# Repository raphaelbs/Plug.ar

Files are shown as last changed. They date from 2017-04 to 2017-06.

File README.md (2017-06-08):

# Plug.ar

Plug.ar é um projeto de conclusão de curso desenvolvido por Raphael Brandão para a Faculdade Pitágoras.

# Descrição

A ideia base do projeto é o desenvolvimento de uma caixa de tomada conectada e modular.

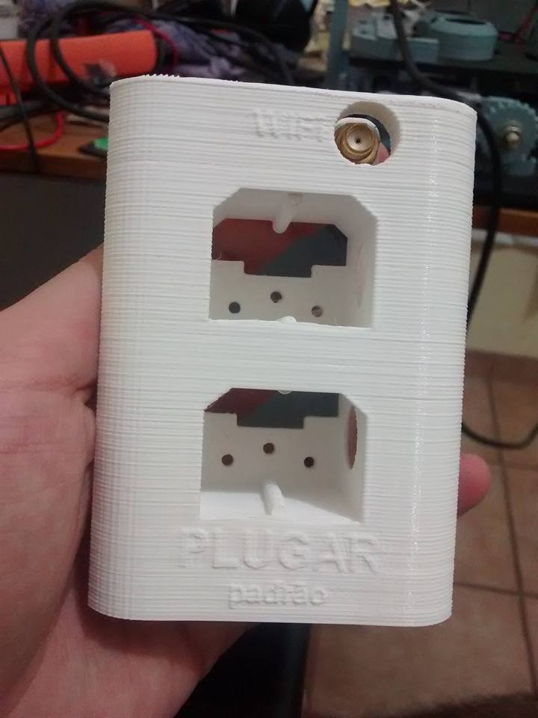
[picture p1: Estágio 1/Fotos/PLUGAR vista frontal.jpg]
Primeira versão do Plug.ar


_Primeira versão do Plug.ar_

### Conectividade

A caixa será concetada à internet através do ESP8266 e também criará uma rede HTTP interna. Esta rede HTTP interna será usada por outros dispositivos Plug.ar da mesma residência para realizar comunicação entre-si mesmo sem acesso à internet.

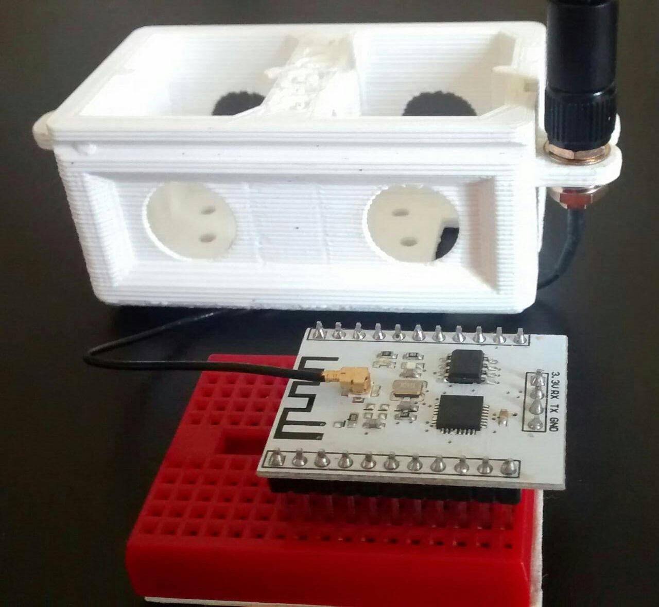
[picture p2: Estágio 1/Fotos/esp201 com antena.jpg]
Plug.ar e o ESP8266


_Plug.ar e o ESP8266_

### Modularização

A caixa de tomada será um container de módulos. O usuário final irá escolher qual módulo utilizar, quando necessário. Por exemplo, se o usuário deseja carregar o celular, poderá inserir um módulo de porta USB diretamente na sua tomada.

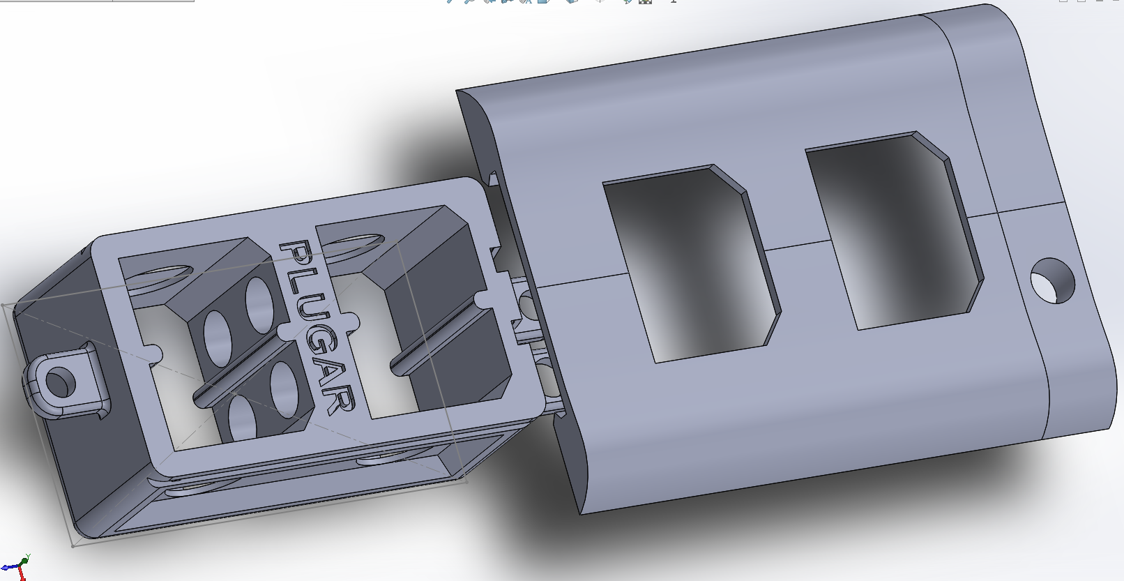
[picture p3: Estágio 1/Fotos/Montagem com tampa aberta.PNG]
Modularização do Plug.ar


_Modularização do Plug.ar_

# Etapas

O projeto conta com 3 etapas:
* [x] 2/2016 [**Estágio 1**](./Estágio%201) estruturação física do projeto com CAD e impressão 3D
* [x] 1/2017 [**Estágio 2**](./Estágio%202) prototipagem eletrônica e interligação com o projeto físico
* [ ] 2/2017 **TCC** desenvolvimento do firmware, cliente web e mobile

# Sobre

Estudante de Engenharia de Controle e Automação - Faculdade Pitágoras.
Gerente de Projetos e Full Stack Developer - Find Soluções Coorporativas LTDA.
Divinópolis, Minas Gerais, Brasil.

_raphael.b.souza@hotmail.com_

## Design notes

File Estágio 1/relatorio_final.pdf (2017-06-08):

### FACULDADE PITÁGORAS

RELATÓRIO DE ESTÁGIO CURRICULAR OBRIGATÓRIO

FACULDADE PITÁGORAS

Aluno: Raphael Brandão de Souza

Curso: Engenharia de Controle e Automação

Matrícula: 828587

Divinópolis

2016

1

RAPHAEL BRANDÃO DE SOUZA

RELATÓRIO DE ESTÁGIO CURRICULAR OBRIGATÓRIO

GUILHERME OTÁVIO FERREIRA FARIA

Relatório de Estágio Curricular apresentado à Faculdade

Pitágoras como requisito parcial do curso de Engenharia de

Controle e Automação.

Coordenador de Curso:

Danielle Comitante Leão Fontes

Divinópolis

2016

2

### FACULDADE PITÁGORAS

Relatório de Estágio Curricular Obrigatório em 2016

Dados do Estagiário

### Nome: Raphael Brandão de Souza

### Registro Acadêmico: 828587

### Curso e Período: Engenharia de Controle e Automação, 8° Período

Dados do Local de Estágio

### Empresa: Guilherme Otávio Ferreira Faria

### Supervisor: Guilherme Otávio Ferreira Faria

### N° de registro: 200649/LP

Período de Estágio

Início: 19/09/2016 | Término: 24/10/2016

Jornadas de trabalho: 30 horas semanais.

Total de horas: 150 horas em 25 dias úteis.

Divinópolis

2016

3

SUMÁRIO

4

### 1 INTRODUÇÃO

O presente trabalho tem como objetivo apresentar o projeto, denominado PLUGAR,

cumprindo a primeira de duas fases da disciplina de Estágio Supervisionado I, que tem como

supervisor o engenheiro Guilherme Otávio Ferreira Faria. Ressalta-se que este projeto é parte

integrantes das disciplinas acadêmicas que estão sendo e serão cursadas na Faculdade Pitágoras

pelo aluno Raphael Brandão do curso de Engenharia de Controle e Automação.

1.1 CENÁRIO

Com a crescente inclusão digital, a necessidade de agregar componentes do dia-a-dia

no mundo digital está sempre em demanda. A Internet das Coisas é um termo que está sendo

repetido cada vez mais nos artigos acadêmicos, nas redes de notícias, projetos de financiamento

coletivo, colaborações open-source, etc. Por definição, Internet das Coisas (IoT - Internet of

Things em inglês) é sinônimo da agregação de componentes simples, básicos e offlines como

geladeiras, carros, cortinas, entre outros, em um ambiente online, controlado e integrado.

Através desta virtualização é possível assumir o controle, economizar tempo, poupar esforços,

em qualquer lugar a qualquer momento, utilizando desde seu smartphone até soluções ainda

mais engenhosas; dependendo apenas da aplicação.

Desta forma, o projeto PLUGAR apoia-se nessa cultura, captando todos os benefícios

de transformar o conceito simplório e estático das tomadas residenciais em um sistema

complexo, integrado, compartilhado e dinâmico, permitindo maximizar o potencial manual e

fixo de controle dos eletrodomésticos, luzes e eletroeletrônicos transformando-os em

componentes vivos de um sistema.

O objetivo cumprido neste estágio inclui a modelagem, análise e impressão 3D do

componente estrutural, planejamento inicial da eletrônica lógica e eletrônica de potência da

placa de circuito impresso do PLUGAR.

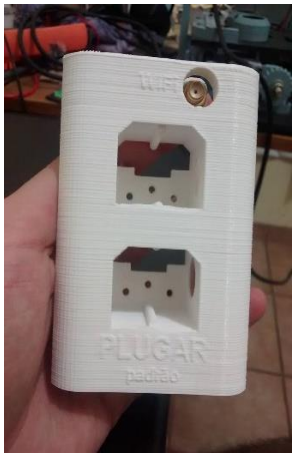
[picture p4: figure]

5

1.2 SOBRE O PLUGAR

PLUGAR é conectar, é vincular, é agregar. O termo reforça a ideia de que é necessária

uma reformulação dos pontos de tomadas e interruptores, a fim de alcançar uma maior

abrangência nas funcionalidades, trazendo tecnologia e maiores níveis de conforto e ergonomia

se comparado ao padrão atual. Este utiliza de recursos manuais e fixos, como por exemplo, o

novo plugue de tomada elétrica de três pinos, regulamentado pela NBR 14136 (Plugues e

tomadas para uso doméstico e análogo até 20A/250V em corrente alternada - padronização).

Além do alto custo, a alteração do padrão gera um movimento desnecessário na indústria para

refatoração dos produtos homologados. No final das contas, além do fato de prejudicar o

consumidor financeiramente por requerer renovação dos produtos adquiridos ou transporte de

adaptadores, este padrão não conta com nenhum tipo de inserção no meio tecnológico.

Unificando os padrões de tomada, o PLUGAR

também adiciona flexibilidade em um novo modelo que

funciona sob a demanda do usuário e inclui tecnologia de

ponta nas residências tirando vantagem da estrutura existente

dos modelos atuais e modificando diretamente a maneira

como interagimos com nossas residências. O objetivo do

dispositivo é integrar, em rede doméstica e na internet, pontos

de interruptores e tomadas, com capacidade à expansão para

pontos de telefone, ethernet, etc. Para incrementar a

usabilidade do dispositivo, o PLUGAR foi projetado com o

ideal de modularidade. Além de funcionar como contêiner de

módulos que variam em funcionalidade, o design do

dispositivo também pode ser adaptado e estendido para fins

específicos (Figura 1).

Figura 1 - PLUGAR visto de frente Fonte: Imagem do autor

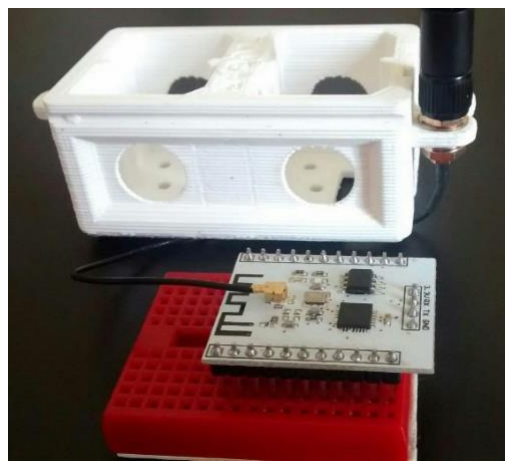
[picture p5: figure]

6

1.3 | TECNOLOGIA APLICADA AO PLUGAR
| Para embasar os conceitos técnicos, deve-se mencionar as referências que se seguem.

1.3.1 MICROCONTROLADORES

Um microcontrolador é um sistema computacional completo, no qual estão incluídos

uma CPU (Unidade de processamento central), memória de dados e programa, um

sistema de clock, portas de I/O (Entrada/Saída), além de outros possíveis periféricos,

tais como, módulos de temporização e conversores A/D entre outros, integrados em

um mesmo componente. (DERNARDIN, [2005], p. 2)

1.3.2 ESP8266 VERSÃO ESP-201

ESP8266 é um microcontrolador com Wi-Fi embutido. Conta com conectores GPIO,

barramentos I2C, SPI, UART, entrada ADC, saída PWM e sensor interno de temperatura. Sua

CPU opera em 80MHz, com possibilidade de operar em 160MHz. Possui arquitetura RISC de

32 bits, 32KBytes de RAM para instruções, 96KBytes de RAM para dados, 64KBytes de ROM

para boot. Possui uma memória Flash SPI Winbond W25Q40BVNIG de 512KBytes. O núcleo

é baseado no IP Diamand Standard LX3 da Tensilica.

Fabricado pela Espressif, existem módulos de diferentes

tamanhos e fabricantes.

O módulo utilizado neste projeto é o ESP-201.

Além das características citadas acima possui dois tipos de

antena: embutida ou conector para UF-L. Também conta

com pinagem padrão de protoboard (distância entre pinos

de 2.54mm) com dimensão totalizando 34x25x3,5mm

(Figura 2).

Figura 2 - ESP8266 versão ESP 201
| Fonte: Imagem do autor

7

1.3.3 PROTOCOLO I2C

O protocolo I2C descreve o funcionamento de um barramento de comunicação serial que utiliza

apenas dois fios, inventado pela Philips no início da década de 90, este protocolo é muito

utilizado para conectar periféricos de baixa velocidade a placas-mãe, microcontroladores e afins.

Tanto a unidade de controle quanto os periféricos devem possuir implementação e suporte I2C,

seja via hardware no próprio microcontrolador ou utilizando CI’s externos como o SC16IS750,

ou até mesmo via software, através de um método chamado bit-bang, onde o funcionamento do

protocolo é emulado bit a bit. (CAMARA, 2013, p.1)

1.3.4 CI PCF8574

O circuito integrado PCF8574 é um extensor de portas entradas/saídas. Funciona sobre

a interface de comunicação I2C, simplificando o circuito em apenas duas portas: serial clock

(SCL) e serial data (SDA).

Com ele é possível expandir as portas de um microcontrolador utilizando apenas essas

duas portas para emular o controle de até 8 portas. Comunica com outros dispositivos I2C

conectados através do registrador que pode conter até 8 estados, uma para cada porta.

1.3.5 PLA

PLA é um material biodegradável produzido a partir de fontes naturais tais como cana

de açúcar e milho, utilizado como matéria prima de impressoras 3D. Grandes peças impressas

com PLA apresentam dimensões precisas e não sofrem com o efeito warp (resfriamento rápido

do material que causa contração). Emite um odor característico de açúcar e não emite nenhum

gás tóxico como pode ser o caso de outros filamentos derivados de plástico.

8

1.4 CONCEITO FUNCIONAL

Cada dispositivo PLUGAR é uma central autônoma capaz de fisicamente controlar os

módulos e integra-los em rede doméstica e/ou via Internet. Para controle e interface com WiFi

o microcontrolador ESP8266 (na sua versão ESP-201) atende os requisitos e se demonstra ideal

pelo baixo custo e integração. A ponte entre o microcontrolador e módulos será feita através do

protocolo I2C utilizando o circuito integrado PCF8574, permitindo a conexão paralela de até 8

módulos sobre o mesmo barramento, reduzindo a complexidade do circuito impresso e

agregando facilidades na padronização dos módulos. No cenário do PLUGAR, um CI I2C de 4

bits atenderia os requisitos.

Os módulos do PLUGAR serão desenvolvidos cada um com sua eletrônica interna,

porém a estruturação do modelo para a eletrônica dos mesmos não será abordada neste trabalho.

1.4.1 ESTRUTURAL

Os componentes estruturais do PLUGAR irão habitar dois tipos de ambientes, o interior

dos pontos de tomada, parcialmente escondido das vistas, e o exterior do ponto de tomada, se

tornando uma ferramenta de design da residência. Neste relatório estão descritas as atividades

desenvolvidas para realização dos componentes estruturais Contêiner e Tampa (Tabela 1).

Tabela 1 - Referência dos componentes, suas funções e localizações

Componente | Função | Localização
Contêiner (Figura 3) | Principal estrutura do PLUGAR. Responsável por substituir a estrutura dentro da caixa de tomada; interliga todos os demais componentes entre si; fixa e conecta o circuito eletrônico com o componente Módulo. Também é estrutura de apoio para o componente Tampa. | Fixado dentro da caixa de tomada.
Tampa | A Tampa além de funcionar como estrutura de design | Encaixado no

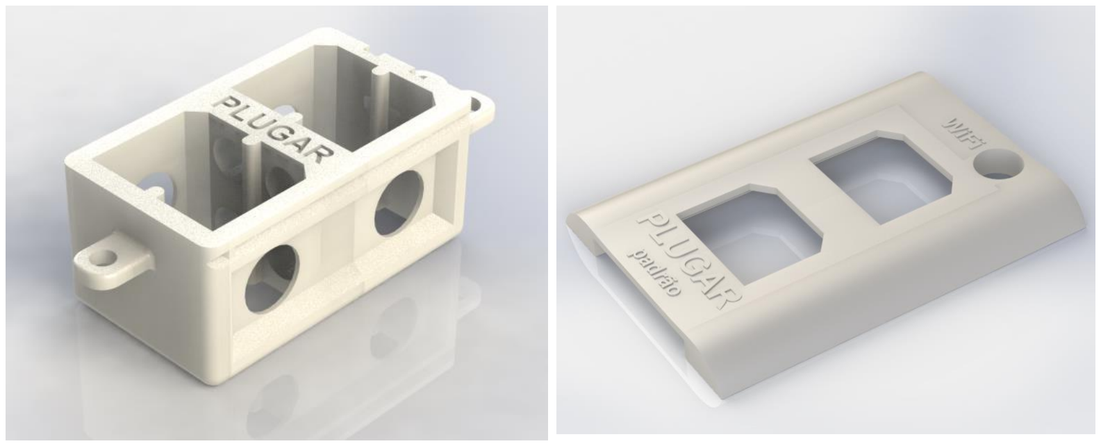
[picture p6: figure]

9

(Figura 4) | também funciona como fixador do componente Módulo dentro do componente Contêiner e como interruptor geral do PLUGAR. Pode assumir formatos variados para incrementar o design do ambiente. | Contêiner.
Módulo | O Módulo é o componente físico que oferece a flexibilidade que o ambiente virtual necessita. Cada Módulo possui sua determinada função e pode ser facilmente substituído do componente Contêiner, basta retirar o componente Tampa, remover o Módulo atual e inserir o desejado. | Inserido no Contêiner.

Fonte: Elaborado pelo autor

Figura 3 - Componente Contêiner, renderizado Fonte: Imagem do autor

Figura 4 - Componente Tampa, renderizado Fonte: Imagem do autor

10

1.4.2 ELETRÔNICA

Do objeto funcional do circuito eletrônico do PLUGAR destaca-se a capacidade de

interligar o microcontrolador ESP8266 versão ESP-201, a cavidade dos módulos e as fontes de

tensão.

O circuito é capaz de converter corrente alternada de alta tensão em corrente contínua

de tensões 5v e 3.3v, redistribuir as faixas de tensões DC e AC para os módulos além de

implementar o barramento I2C para comunicação.

Tabela 2 - Detalhamento dos componentes eletrônicos e suas funções

Nome | Descrição | Características
HLK-PM12 (Figura 5) | Conversor integrado AC para DC. | • Opera com tensões AC entre 90v e 264v. • Eficiente, perde menos que 0.1W quando em standby. • Fornece 600mA de corrente estavelmente e aguenta picos de 1A.
L4931 (Figura 6) | Regulador de tensão pacote TO-92. | • Regula tensões com até 2% de tolerância. • Corrente máxima de 300mA com circuito interno limitador de corrente e switch térmico.
BCI 006 1E-6 (Figura 7) | Barra de pinos macho-fêmea padrão protoboard com 6 saídas. | • Conector de encaixe linear. • Baixo custo.
Terminais parafusados (Figura 8) | Borne integradas com circuito impresso. | • Praticidade • Baixo custo

Fonte: Elaborado pelo autor

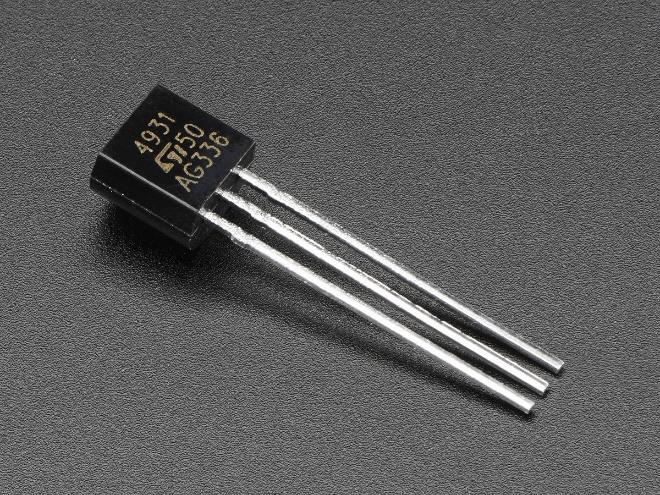
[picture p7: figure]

11

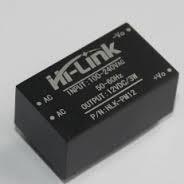
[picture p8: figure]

Figura 5- HLK-PM12
Fonte: http://www.hlktech.net/product_detail.php?ProId=56

Figura 6 - L4931.
Fonte: https://www.adafruit.com/product/2236

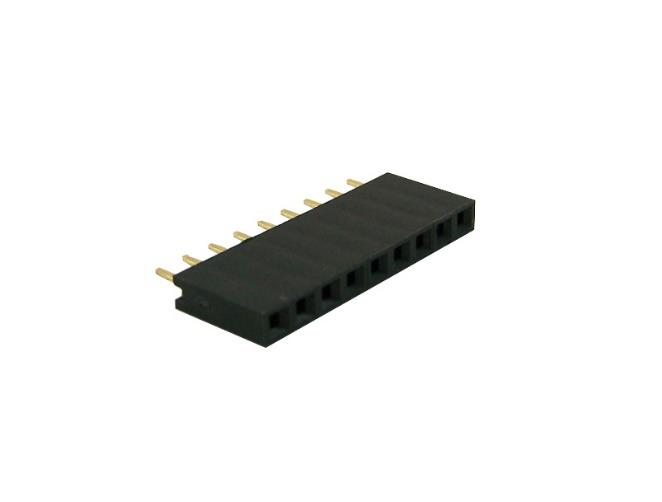
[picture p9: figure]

Figura 7 - BCI 006 1E-6
Fonte: http://www.eletrodex.com.br/barra-conectora-de-pino-estampado-simples-180-2-a-40-pinos.html (http://www.eletrodex.com.br/barra-conectora-de-pino-estampado-simples-180-2-a-40-pinos.html)

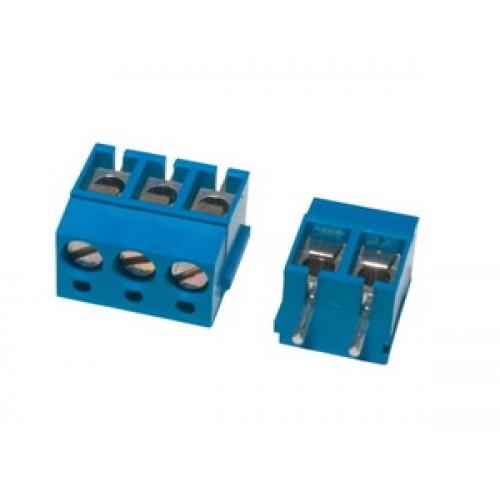
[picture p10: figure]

Figura 8 - Terminais parafusados
Fonte: http://www.taydaelectronics.com/dg300-screw-terminal-block-2-positions-5mm.html (http://www.taydaelectronics.com/dg300-screw-terminal-block-2-positions-5mm.html)

### 2 AMBIENTE DE ESTÁGIO

Guilherme Otávio Ferreira Faria é membro colaborador de uma firma autônoma

prestadora de serviço na área de engenharia e construção civil.

A firma realiza projetos arquitetônicos, projetos elétricos, projetos de prevenção e

combate a incêndio, projetos estruturais e planejamentos e execuções de obras. Presta serviço

para Francisco Imóveis, Martins Empreendimentos, Construtora e Incorporadora Predisul,

Construtora e Incorporadora Premium, dentre outros. Situa-se na Rua Pernambuco, número 50,

bairro Centro da cidade de Divinópolis. Sua missão é executar com maestria obras e projetos

na área de construção civil.

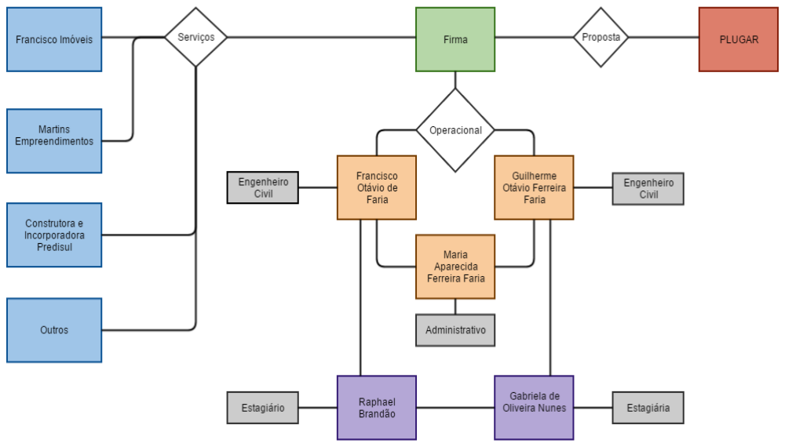
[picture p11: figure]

12

Atualmente, buscando expandir a abrangência na prestação de serviço, realizou-se uma

parceria para desenvolver um projeto de automação residencial: o PLUGAR, combinando a

expertise dos serviços realizados pela firma e o conhecimento do aluno aplicado na área de

automação, controle, modelagem, eletrônica e impressão 3D.

O ambiente de estágio conta com estações de qualidade uma vez que na empresa são

utilizados softwares robustos de CAD para o desenvolvimento dos projetos de engenharia civil.

2.1 | ORGANOGRAMA
| De acordo com o ambiente de estágio citado no item 2, foi possível estabelecer um

organograma, no qual apresenta a organização hierárquica da empresa, seus setores e

funcionamentos por meio de cores (Figura 9).

Figura 9 - Organograma da firma Fonte: Elaborado pelo autor

13

### 3 ATIVIDADES DESENVOLVIDAS

### 19/09/2016 – Apresentação

Introdução à metodologia, ambientação e compartilhamento dos recursos necessários para o

desenvolvimento durante o estágio.

### 20/09/2016 – Resolução conceitual

Apresentação dos conceitos, desafios técnicos, áreas de atuação para desenvolvimento do

projeto, recursos necessários e capacidades requeridas.

### Período de 21/09/2016 a 22/09/2016 – Discussão e detalhamento

Estruturação inicial das etapas necessárias para desenvolvimento linear do projeto.

Observações sobre a necessidade do primeiro esboço técnico do circuito impresso para

modelagem do modelo estrutural. Padronização para o tamanho do contêiner com

40x70x32mm. Contemplação e subdivisão do cronograma do projeto no tempo das etapas do

estágio supervisionado e trabalho de conclusão de curso que se seguem entre o segundo

semestre de 2016 ao segundo semestre de 2017.

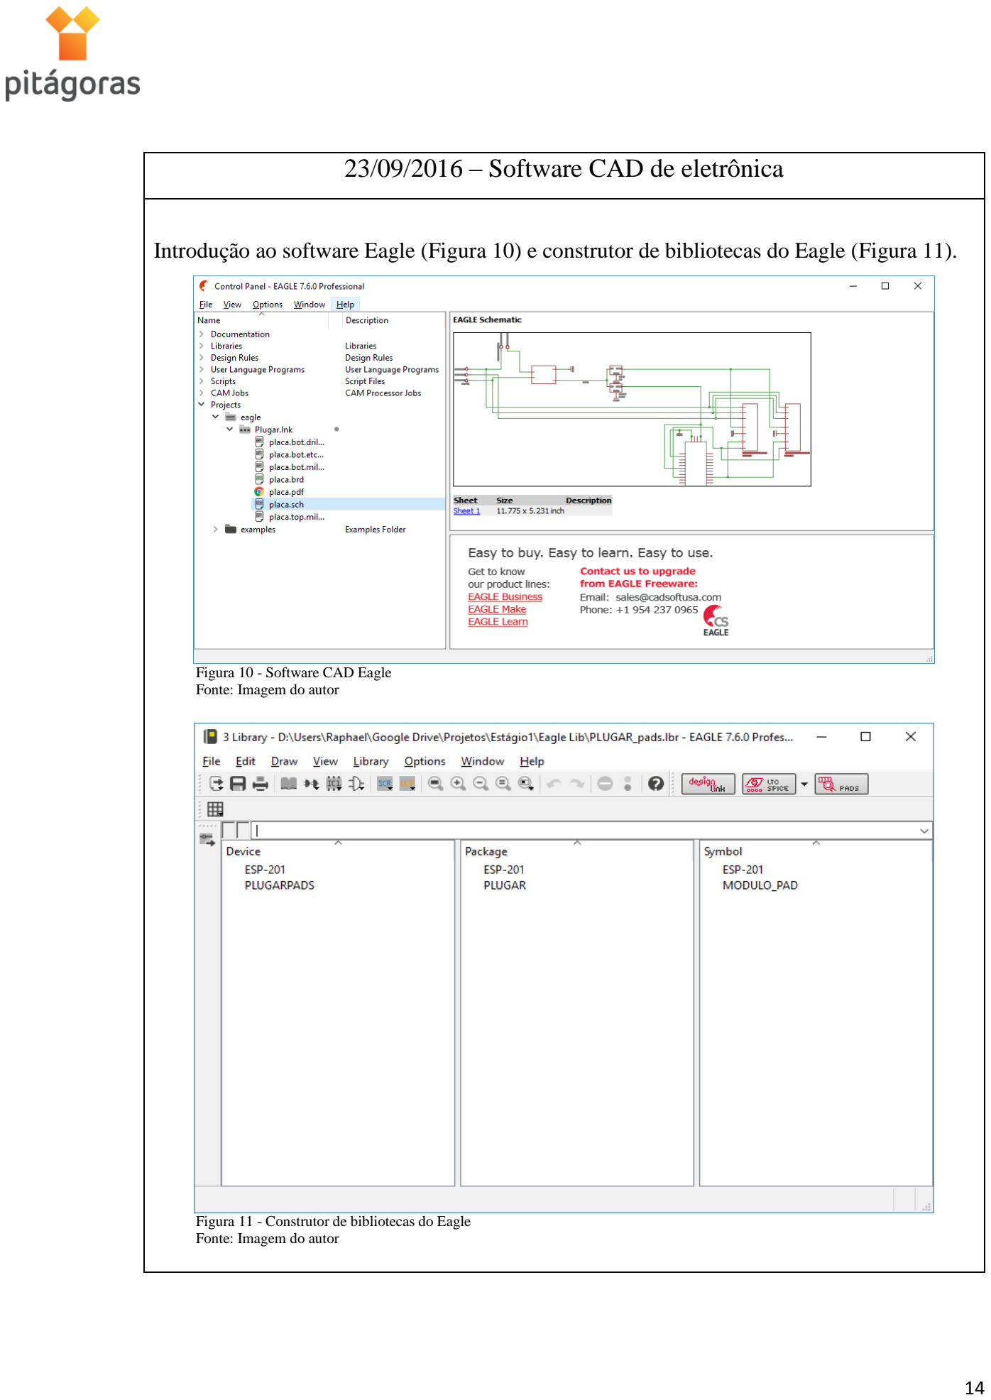
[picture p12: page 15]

14

### 23/09/2016 – Software CAD de eletrônica

Introdução ao software Eagle (Figura 10) e construtor de bibliotecas do Eagle (Figura 11).

Figura 10 - Software CAD Eagle Fonte: Imagem do autor

Figura 11 - Construtor de bibliotecas do Eagle Fonte: Imagem do autor

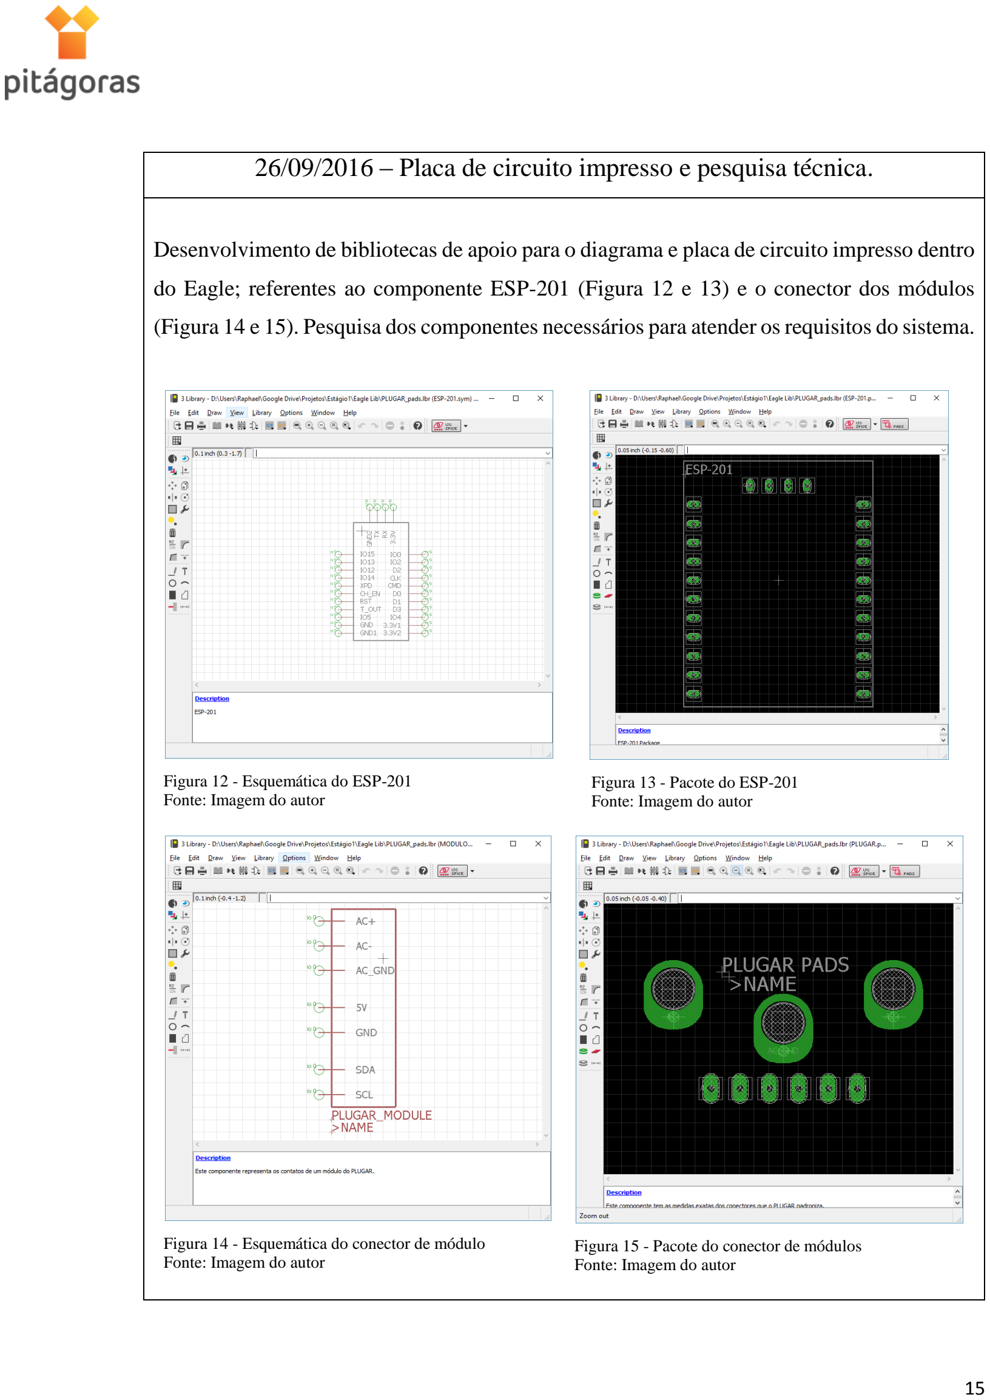
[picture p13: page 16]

15

26/09/2016 – Placa de circuito impresso e pesquisa técnica.

Desenvolvimento de bibliotecas de apoio para o diagrama e placa de circuito impresso dentro

do Eagle; referentes ao componente ESP-201 (Figura 12 e 13) e o conector dos módulos

(Figura 14 e 15). Pesquisa dos componentes necessários para atender os requisitos do sistema.

Figura 12 - Esquemática do ESP-201 Fonte: Imagem do autor

Figura 13 - Pacote do ESP-201 Fonte: Imagem do autor

Figura 14 - Esquemática do conector de módulo Fonte: Imagem do autor

Figura 15 - Pacote do conector de módulos Fonte: Imagem do autor

16

### 27/09/2016 – Placa de circuito

Integração dos componentes escolhidos no circuito esquematizado (Figura 16) com base nas

medidas pré-estabelecidas (Figura 17). Modelagem da placa de circuito impresso (Figura 18).

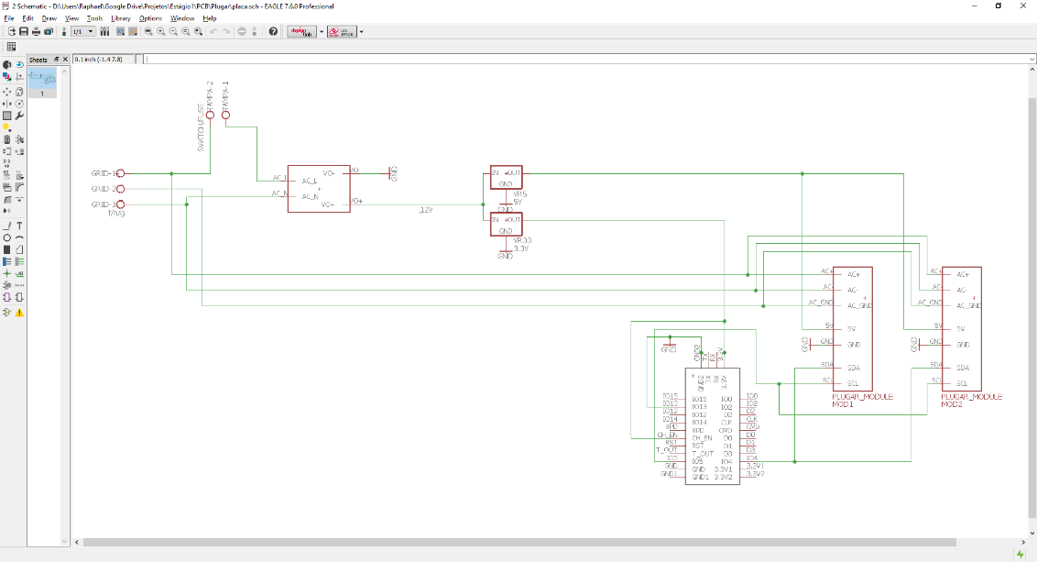
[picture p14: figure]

Figura 16 - Esquema eletrônico Fonte: Imagem do autor

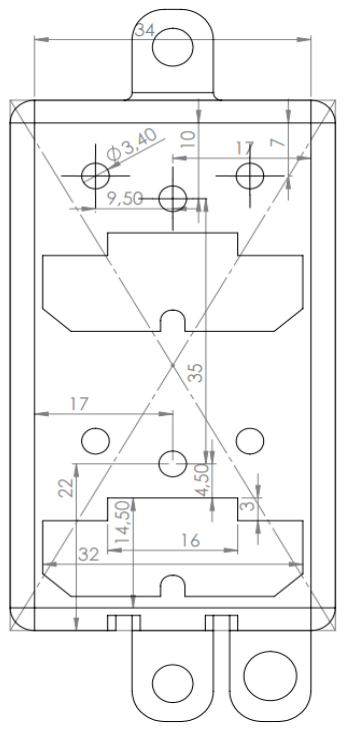
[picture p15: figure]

Figura 17 - Padrão estabelecido Fonte: Imagem do autor

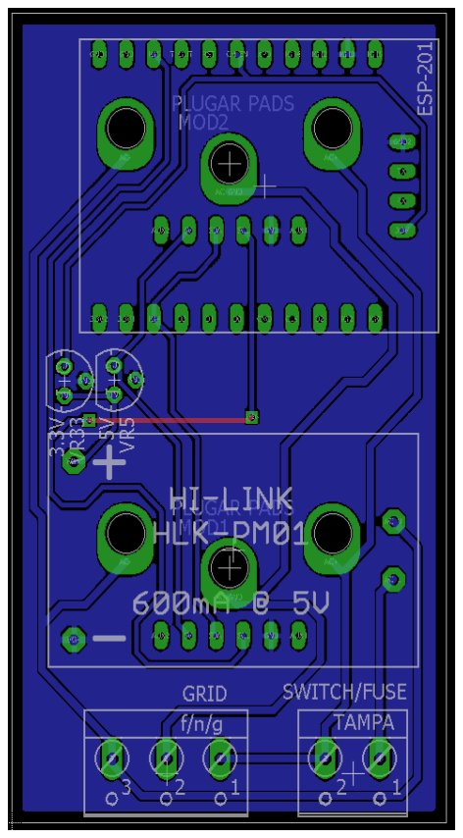
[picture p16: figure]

Figura 18 - Placa de circuito impresso do PLUGAR
. | Fonte: Imagem do autor

17

### 28/09/2016 – Introdução ao CAD 3D

Conferência do modelo gerado através do software Eagle com o padrão desejado. Introdução

ao software de modelagem 3D SolidWorks (Figura 19).

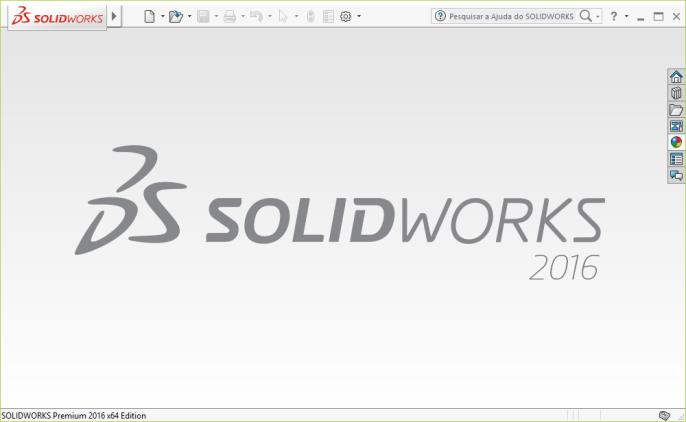
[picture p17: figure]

Figura 19 - Software CAD 3D Solidwoks Fonte: Imagem do autor

### Período de 29/09/2016 a 05/10/2016 – Componente Contêiner

Com base no modelo eletrônico e o desenho técnico do padrão estabelecido, foi desenvolvido

o componente estrutural Contêiner (Figura 20) contemplando métrica para conter os

componentes Módulos, orelhas fixadoras de parede, orelhas fixadoras para a antena, conceito

para trilha de contato liga/desliga de ação com o componente Tampa e trilha de apoio para o

componente Tampa.

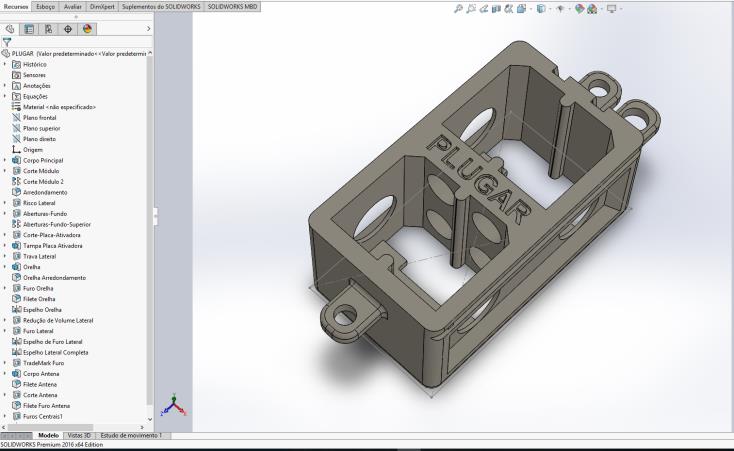
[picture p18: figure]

Figura 20 - Componente Contêiner, segunda versão Fonte: Imagem do autor

18

### Período de 06/10/2016 a 10/10/2016 – Componente Tampa

Implementação do componente Tampa (Figura 21) com design orgânico, furação para uso

dos módulos e da antena, trilha para apoio no componente Contêiner e implementação dos

textos informativos. Avaliação do resultado obtido.

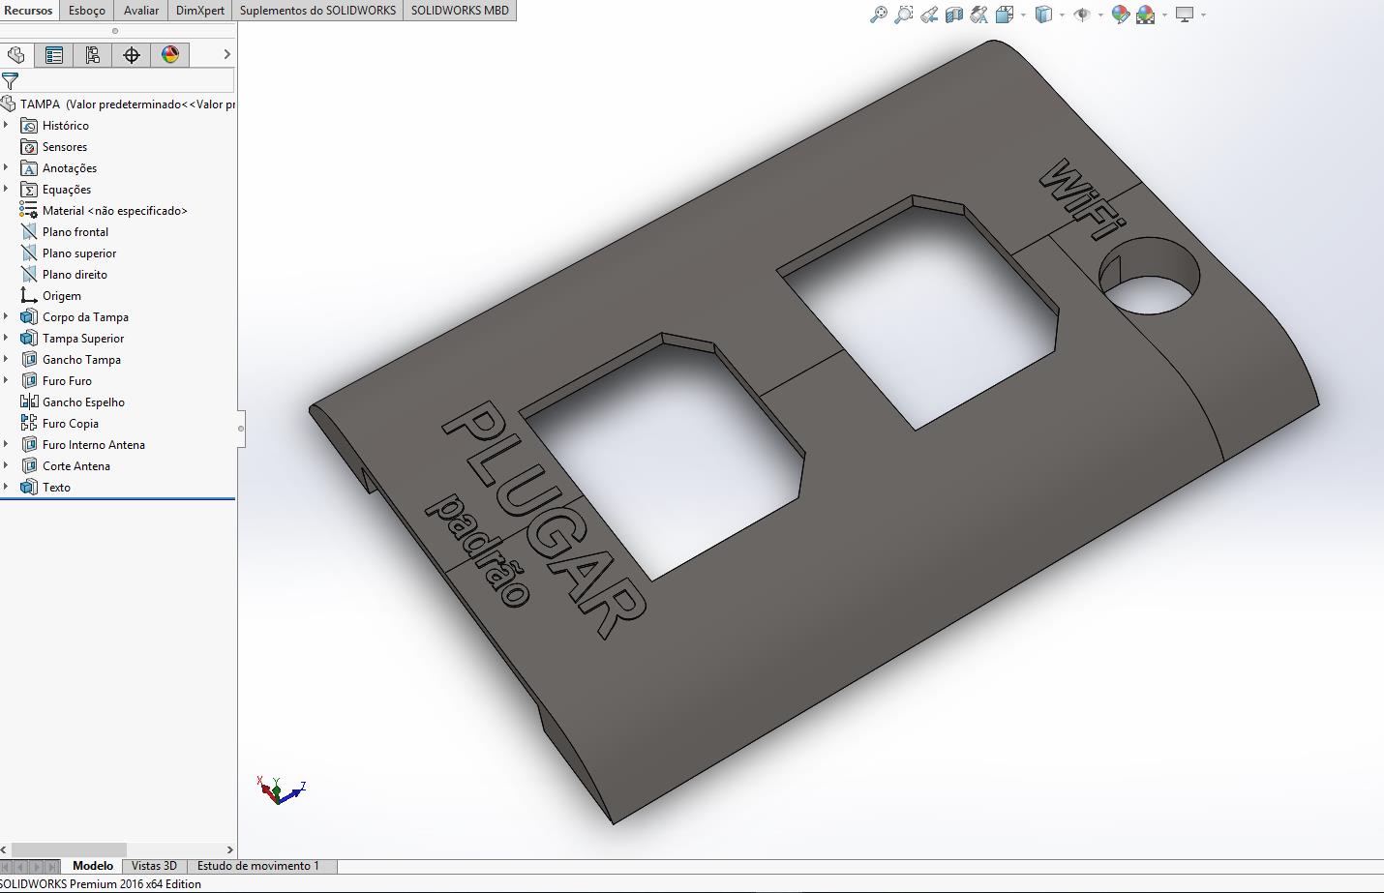
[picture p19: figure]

Figura 21 - Componente Tampa, segunda versão Fonte: Imagem do autor

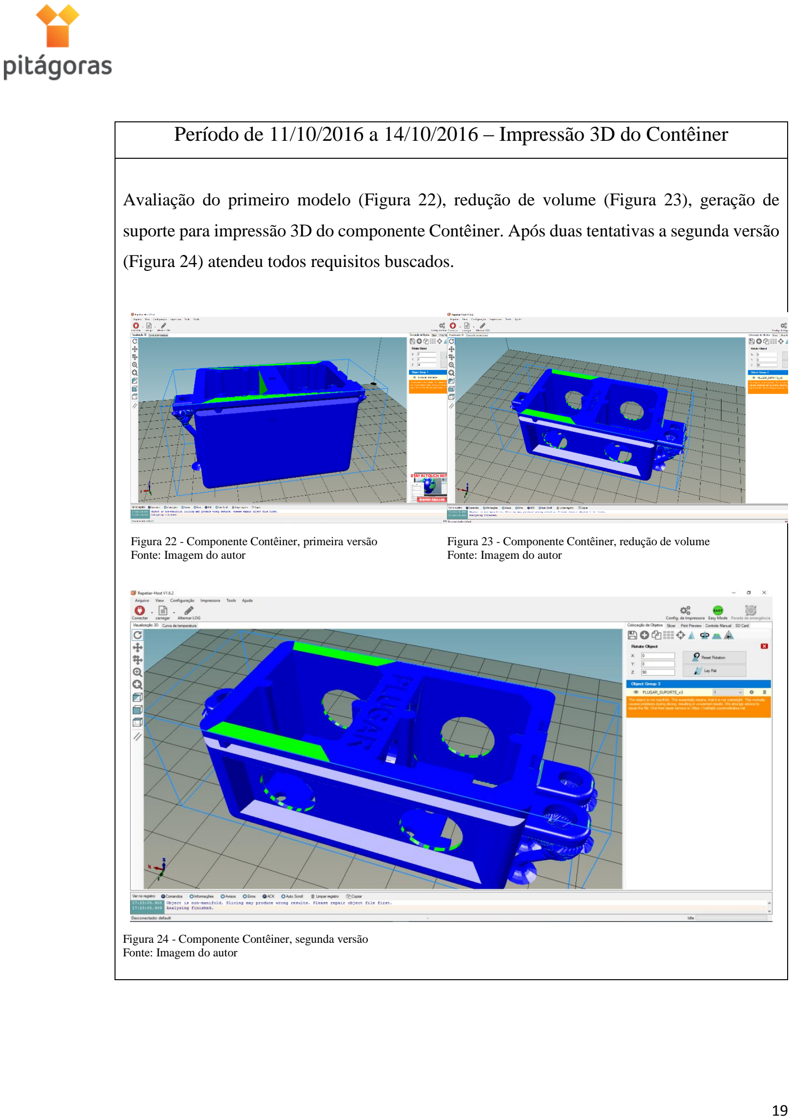
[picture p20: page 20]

19

### Período de 11/10/2016 a 14/10/2016 – Impressão 3D do Contêiner

Avaliação do primeiro modelo (Figura 22), redução de volume (Figura 23), geração de

suporte para impressão 3D do componente Contêiner. Após duas tentativas a segunda versão

(Figura 24) atendeu todos requisitos buscados.

Figura 22 - Componente Contêiner, primeira versão Fonte: Imagem do autor

Figura 23 - Componente Contêiner, redução de volume Fonte: Imagem do autor

Figura 24 - Componente Contêiner, segunda versão Fonte: Imagem do autor

20

### Período de 17/10/2016 a 18/10/2016 – Componente Tampa

Avaliação do primeiro modelo (Figura 25), conferência do encaixe com o componente

Contêiner, adequação e impressão da segunda versão com folga no trilho e aumento do

orifício da antena (Figura 26).

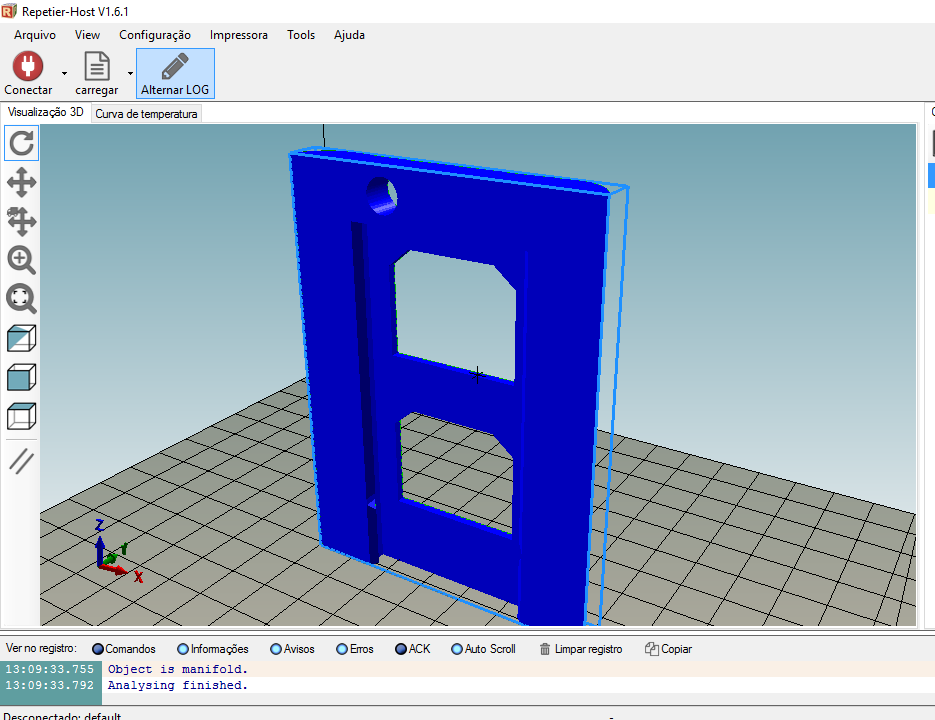
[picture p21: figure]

Figura 25 - Componente Tampa, primeira versão Fonte: Imagem do autor

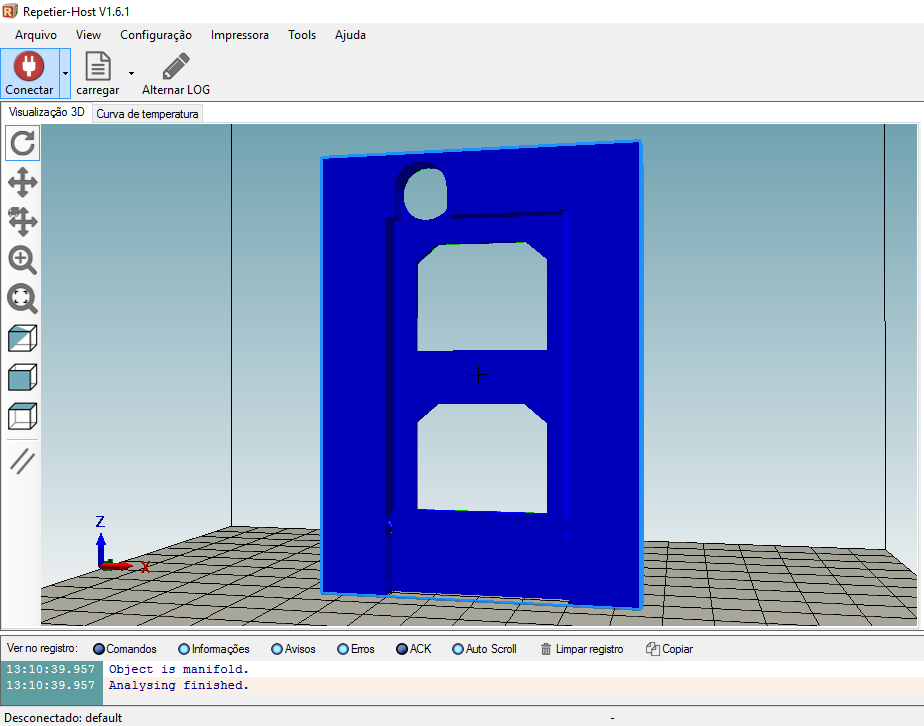
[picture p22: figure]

Figura 26 - Componente Tampa, segunda versão Fonte: Imagem do autor

21

### 20/10/2016 – Análise de desempenho dos modelos estabelecidos

Com base nas versões previamente estabelecidas, fora testado o atendimento dos objetivos

requeridos. O encaixe do componente Contêiner para o componente Tampa está funcional,

contando com travas que cumpriram sua função (Figura 27); a altura do componente

Contêiner ficou correta para atender o padrão das caixas de tomada (Figura 29); métrica do

componente Tampa ficou dentro dos padrões atuais (Figura 28).

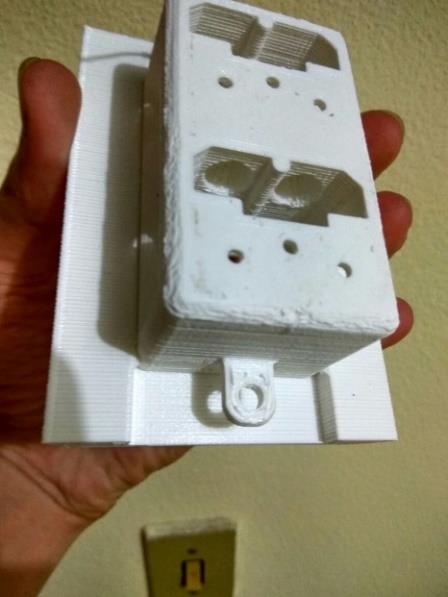
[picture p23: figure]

Figura 27 - Encaixe da Tampa no Contêiner. Fonte: Imagem do autor

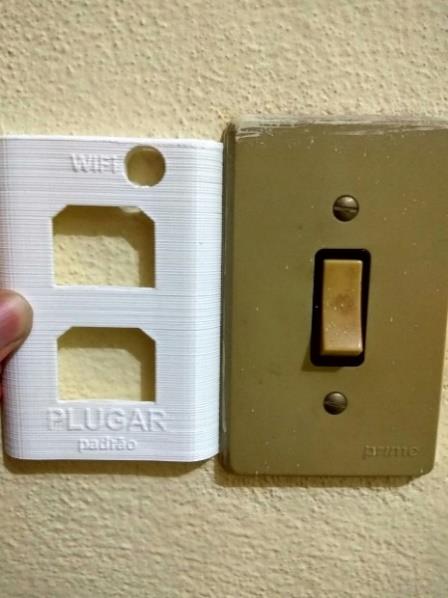
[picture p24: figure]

Figura 28 - Comparativo do componente Tampa com uma tampa de tomada.
Fonte: Imagem do autor

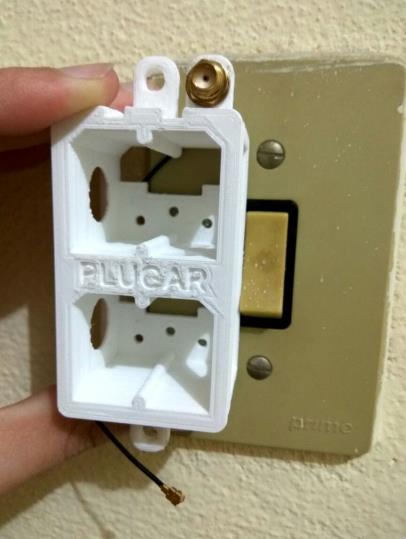
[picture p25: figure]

Figura 29 - Comparativo superficial do componente Contêiner com uma tomada Fonte: Imagem do autor

22

### 4 DISCUSSÕES GERAIS

Com a popularização dos movimentos Maker pelo mundo, a difusão da tecnologia open-

source reflete em qualificação técnica informal e gratuita. Gera uma cadeia de consequências,

desde novas ideias, novos produtos até novos padrões de mercado na própria comunidade.

Grandes contribuições do mundo Maker devem ser citadas aqui pois são cruciais para o projeto

PLUGAR. Os padrões de componentes de impressora 3D possibilitaram a montagem da

impressora 3D Graber i3 utilizada no estágio. Com a ajuda deste recurso foi possível expandir

o projeto para o meio físico, testando iterações dos modelos até encontrar os resultados

desejados.

4.1 | DO PROJETO
| O PLUGAR evoluiu de um pressuposto inicial simples, sem modularização, apenas com

conceito de integração com a internet. Evoluiu em sua estrutura física e ainda conta com um

grande caminho a percorrer quanto a implementação do sistema de controle, a agregação e

montagem dos componentes.

| Os recursos utilizados no projeto proveram tanto da empresa quanto do aluno. Os

softwares pagos como Eagle e Solidworks foram utilizados na empresa por serem licenciados

para uso doméstico e comercial. Os softwares livres tais como Repetier Host, Slic3r,

Meshmixer e Blender foram utilizados pelo aluno. A impressora 3D é propriedade do aluno,

porém toda prototipagem fora feita sob supervisão do engenheiro para avaliação do

atendimento dos requisitos.

4.2 DO AMBIENTE DE ESTÁGIO

Sendo amigos de longa data, o relacionamento entre supervisor e aluno se mostrou

simplificado, divertido e direto. A troca de informações, conhecimento e opiniões é suavizada

pela familiaridade com o companheiro de serviço tanto no momento de delegar funções quanto

no momento de buscar ajuda.

23

Mesmo atarefado constantemente em projetos paralelos o supervisor do estágio soube

repassar e avaliar as atividades no momento necessário e assegurou o cumprimento do

cronograma estabelecido.

### 5 CONSIDERAÇÕES FINAIS

Inspirado em novas vertentes do setor de tecnologia, o projeto PLUGAR se mostrou

como um desafio, bem como, excelente ponto de iniciação no mercado profissional, embasando

novas áreas além da capacitação curricular do aluno e expandindo a área de interesse e atuação

do mesmo. Participar, desenvolver e criar, desde o conceito até a realidade, foram metodologias

de trabalho gratificantes e, de certa forma, pioneiras.

Por meio do estágio supervisionado, que se finaliza através da documentação de relatório, foi

possível alcançar um aprendizado extracurricular além de instigar e fomentar o estudo e

interesse em diferentes áreas ímpares às comuns.

### 6 REFERÊNCIAS

ALLDATASHEET, L4931 – Very Low Dropout Voltage Regulator, Datasheet (PDF) –

STMicroeletronics. Disponível em

<http://pdf1.alldatasheet.com/datasheet-

pdf/view/22466/STMICROELECTRONICS/L4931.html>. (http://pdf1.alldatasheet.com/datasheet-pdf/view/22466/STMICROELECTRONICS/L4931.html) Acesso em 26 de setembro de

2016.

CAMARA, Rômulo. Barramento e Protocolo I2C. Juazeiro, BA: Univasf. 2013. p. 1-3.

Disponível em:

<http://www.univasf.edu.br/~romulo.camara/novo/wp-content/uploads/2013/11/Barramento-

e-Protocolo-I2C.pdf>. (http://www.univasf.edu.br/~romulo.camara/novo/wp-content/uploads/2013/11/Barramento-e-Protocolo-I2C.pdf) Acesso em 28 de novembro de 2016.

24

DENARDIN, Gustavo Weber. Microcontroladores. Joinville, SC: Udesc. [2005], p. 1-34.

Disponível em:

<http://www.joinville.udesc.br/portal/professores/eduardo_henrique/materiais/apostila_micro

_do_Gustavo_Weber.pdf>. (http://www.joinville.udesc.br/portal/professores/eduardo_henrique/materiais/apostila_micro_do_Gustavo_Weber.pdf) Acesso em 28 de novembro de 2016.

ESPRESSIF, ESP8266EX. Disponível em:

<https://espressif.com/en/products/hardware/esp8266ex/overview>. Acesso em 19 de setembro

de 2016.

ESP8266, Community Forum. Disponível em <http://www.esp8266.com/>. Acesso em 19 de

setembro de 2016.

MESHMIXER: GENERATE SUPPORTS. Disponível em:

<http://www.instructables.com/id/Meshmixer-Generate-Supports/>. Acesso em 11 de outubro

de 2016.

SILVA, Tarcisio. Introdução ao CadSoft Eagle. 2016.

Disponível em: <https://www.embarcados.com.br/tutorial-eagle-introducao/>. Acesso em 22

de setembro de 2016.

TEXAS INSTRUMENTS, PCF8574 Remote 8-Bit I/O Expander for I2C Bus. 2015. Disponível

em: <http://www.ti.com/lit/ds/symlink/pcf8574.pdf>. Acesso em 26 de setembro de 2016.

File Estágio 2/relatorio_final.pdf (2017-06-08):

### FACULDADE PITÁGORAS

RELATÓRIO DE ESTÁGIO CURRICULAR OBRIGATÓRIO

FACULDADE PITÁGORAS

Aluno: Raphael Brandão de Souza

Curso: Engenharia de Controle e Automação

Matrícula: 82858767489

Divinópolis

2017

1

RAPHAEL BRANDÃO DE SOUZA

RELATÓRIO DE ESTÁGIO CURRICULAR OBRIGATÓRIO

GUILHERME OTÁVIO FERREIRA FARIA

Relatório de Estágio Curricular apresentado à Faculdade

Pitágoras como requisito parcial do curso de Engenharia de

Controle e Automação.

Coordenador de Curso:

Rodrigo Comitante Leão

Divinópolis

2017

2

### FACULDADE PITÁGORAS

Relatório de Estágio Curricular Obrigatório em 2017

Dados do Estagiário

### Nome: Raphael Brandão de Souza

### Registro Acadêmico: 82858767489

### Curso e Período: Engenharia de Controle e Automação, 9° Período

Dados do Local de Estágio

### Empresa: Guilherme Otávio Ferreira Faria

### Supervisor: Guilherme Otávio Ferreira Faria

### N° de registro: 200649/LP

Período de Estágio

Início: 03/04/2017 | Término: 10/05/2017

Jornadas de trabalho: 30 horas semanais.

Total de horas: 150 horas em 25 dias úteis.

Divinópolis

2017

3

SUMÁRIO

4

### 1 INTRODUÇÃO

O presente trabalho tem como objetivo apresentar o projeto, denominado PLUGAR,

cumprindo a segunda de duas fases da disciplina de Estágio Supervisionado II, que tem como

supervisor o engenheiro Guilherme Otávio Ferreira Faria. Ressalta-se que este projeto é parte

integrantes das disciplinas acadêmicas que estão sendo e serão cursadas na Faculdade Pitágoras

pelo aluno Raphael Brandão do curso de Engenharia de Controle e Automação.

1.1 CENÁRIO

Com a crescente inclusão digital, a necessidade de agregar componentes do dia-a-dia

no mundo digital está sempre em demanda. A Internet das Coisas é um termo que está sendo

repetido cada vez mais nos artigos acadêmicos, nas redes de notícias, projetos de financiamento

coletivo, colaborações open-source, etc. Por definição, Internet das Coisas (IoT - Internet of

Things em inglês) é sinônimo da agregação de componentes simples, básicos e offlines como

geladeiras, carros, cortinas, entre outros, em um ambiente online, controlado e integrado.

Através desta virtualização é possível assumir o controle, economizar tempo, poupar esforços,

em qualquer lugar a qualquer momento, utilizando desde seu smartphone até soluções ainda

mais engenhosas; dependendo apenas da aplicação.

Desta forma, o projeto PLUGAR apoia-se nessa cultura, captando todos os benefícios

de transformar o conceito simplório e estático das tomadas residenciais em um sistema

complexo, integrado, compartilhado e dinâmico, permitindo maximizar o potencial manual e

fixo de controle dos eletrodomésticos, luzes e eletroeletrônicos transformando-os em

componentes vivos de um sistema.

O objetivo cumprido neste estágio inclui a modelagem, análise e impressão 3D módulo

de interruptor, aperfeiçoamento das estruturas previamente desenhadas e desenvolvimento e

fabricação da eletrônica lógica e eletrônica de potência da placa de circuito impresso do

PLUGAR.

5

1.2 SOBRE O PLUGAR

PLUGAR é conectar, é vincular, é agregar. O termo reforça a ideia de que é necessária

uma reformulação dos pontos de tomadas e interruptores, a fim de alcançar uma maior

abrangência nas funcionalidades, trazendo tecnologia e maiores níveis de conforto e ergonomia

se comparado ao padrão atual. Este utiliza de recursos manuais e fixos, como por exemplo, o

novo plugue de tomada elétrica de três pinos, regulamentado pela NBR 14136 (Plugues e

tomadas para uso doméstico e análogo até 20A/250V em corrente alternada - padronização).

Além do alto custo, a alteração do padrão gera um movimento desnecessário na indústria para

refatoração dos produtos homologados. No final das contas, além do fato de prejudicar o

consumidor financeiramente por requerer renovação dos produtos adquiridos ou transporte de

adaptadores, este padrão não conta com nenhum tipo de inserção no meio tecnológico.

Unificando os padrões de tomada, o PLUGAR também adiciona flexibilidade em um

novo modelo que funciona sob a demanda do usuário e inclui

tecnologia de ponta nas residências tirando vantagem da

estrutura existente dos modelos atuais e modificando

diretamente a maneira como interagimos com nossas

residências. O objetivo do dispositivo é integrar, em rede

doméstica e na internet, pontos de interruptores e tomadas,

com capacidade à expansão para pontos de telefone, ethernet,

etc. Para incrementar a usabilidade do dispositivo, o

PLUGAR foi projetado com o ideal de modularidade. Além

de funcionar como contêiner de módulos que variam em

funcionalidade, o design do dispositivo também pode ser

adaptado e estendido para fins específicos (Figura 1).
Figura 1 - PLUGAR visto de frente Fonte: Imagem do autor.

6

1.3 | TECNOLOGIA APLICADA AO PLUGAR
| Para embasar os conceitos técnicos, deve-se mencionar as referências que se seguem.

1.3.1 MICROCONTROLADORES

Um microcontrolador é um sistema computacional completo, no qual estão incluídos

uma CPU (Unidade de processamento central), memória de dados e programa, um

sistema de clock, portas de I/O (Entrada/Saída), além de outros possíveis periféricos,

tais como, módulos de temporização e conversores A/D entre outros, integrados em

um mesmo componente. (DERNARDIN, [2005], p. 2)

1.3.2 ESP8266 VERSÃO ESP-201

ESP8266 é um microcontrolador com Wi-Fi embutido. Conta com conectores GPIO,

barramentos I2C, SPI, UART, entrada ADC, saída PWM e sensor interno de temperatura. Sua

CPU opera em 80MHz, com possibilidade de operar em 160MHz. Possui arquitetura RISC de

32 bits, 32KBytes de RAM para instruções, 96KBytes de RAM para dados, 64KBytes de ROM

para boot. Possui uma memória Flash SPI Winbond W25Q40BVNIG de 512KBytes. O núcleo

é baseado no IP Diamand Standard LX3 da Tensilica.

Fabricado pela Espressif, existem módulos de diferentes

tamanhos e fabricantes.

O módulo utilizado neste projeto é o ESP-201. Além

das características citadas acima possui dois tipos de antena:

embutida ou conector para UF-L. Também conta com

pinagem padrão de protoboard (distância entre pinos de

2.54mm) com dimensão totalizando 34x25x3,5mm (Figura

2).

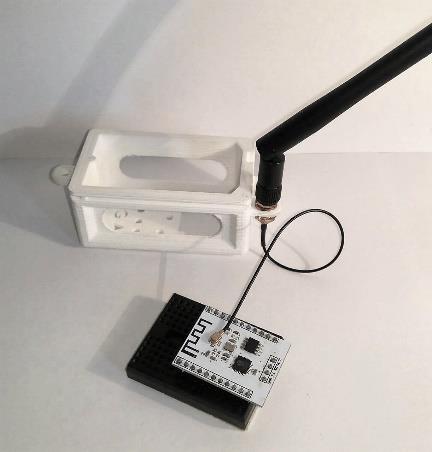
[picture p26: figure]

Figura 2 - ESP8266 versão ESP 201 Fonte: Imagem do autor

7

1.3.3 PROTOCOLO I2C

O protocolo I2C descreve o funcionamento de um barramento de comunicação serial

que utiliza apenas dois fios, inventado pela Philips no início da década de 90, este

protocolo é muito utilizado para conectar periféricos de baixa velocidade a placas-mãe,

microcontroladores e afins. Tanto a unidade de controle quanto os periféricos devem

possuir implementação e suporte I2C, seja via hardware no próprio microcontrolador

ou utilizando CI’s externos como o SC16IS750, ou até mesmo via software, através de

um método chamado bit-bang, onde o funcionamento do protocolo é emulado bit a bit.

(CAMARA, 2013, p.1)

1.3.4 CI PCF8574

O circuito integrado PCF8574 é um extensor de portas entradas/saídas. Funciona sobre

a interface de comunicação I2C, simplificando o circuito em apenas duas portas: serial clock

(SCL) e serial data (SDA).

Com ele é possível expandir as portas de um microcontrolador utilizando apenas essas

duas portas para emular o controle de até 8 portas. Comunica com outros dispositivos I2C

conectados através do registrador que pode conter até 8 estados, uma para cada porta.

1.3.5 PLA

PLA é um material biodegradável produzido a partir de fontes naturais, tais como, cana

de açúcar e milho, utilizado como matéria prima de impressoras 3D. Grandes peças impressas

com PLA apresentam dimensões precisas e não sofrem com o efeito warp (resfriamento rápido

do material que causa contração). Emite um odor característico de açúcar e não emite nenhum

gás tóxico como pode ser o caso de outros filamentos derivados de plástico.

8

1.3.6 ROUTER CNC

Router em inglês, refere-se ás tão conhecidas Tupias, que são utilizadas para realizar

trabalhos manuais em madeiras, através de ferramentas especificas. CNC é a sigla do

inglês Computer Numeric Control, em português, Controle Número Computadorizado. É um sistema de controle de máquina, realizado através de um computador, e utilizado

em tornos e centros de usinagem. Router CNC é uma máquina controlada através de

um computador, tendo como principais aplicações, trabalhos com madeiras, plásticos,

borrachas, metais não ferrosos, espumas, entre outros. (JARAGUACNC, 2017, p.1)

1.3.7 GCODE

Gcode é um padrão de texto digital que representa movimentos em coordenadas

cartesianas. Estes textos comumente são utilizados em máquinas micro controladas. Podem ser

trafegados via comunicação serial entre um computador e circuitos controladores dedicados.

Nesta etapa do estágio utilizou-se o gcode para comandar a Router CNC.

1.4 CONCEITO FUNCIONAL

Cada dispositivo PLUGAR é uma central autônoma capaz de fisicamente controlar os

módulos e integra-los em rede doméstica e/ou via Internet. Para controle e interface com WiFi

o microcontrolador ESP8266 (na sua versão ESP-201) atende os requisitos e se demonstra ideal

pelo baixo custo e integração. A ponte entre o microcontrolador e módulos será feita através do

protocolo I2C utilizando o circuito integrado PCF8574, permitindo a conexão paralela de até 8

módulos sobre o mesmo barramento, reduzindo a complexidade do circuito impresso e

agregando facilidades na padronização dos módulos. No cenário do PLUGAR, um circuito

integrado I2C de 4 bits atenderia os requisitos.

Nesta etapa será apresentado o módulo de interruptor com sua estrutura física e o

circuito elétrico responsável pelo controle e interligação com o componente primário do

PLUGAR.

9

1.4.1 ESTRUTURAL

Os componentes estruturais do PLUGAR irão habitar dois tipos de ambientes, o interior

dos pontos de tomada, parcialmente escondido das vistas, e o exterior do ponto de tomada, se

tornando uma ferramenta de design da residência. Neste relatório estão descritas as atividades

desenvolvidas para realização do componente estrutural Módulo Interruptor e aperfeiçoamento

necessário do componente estrutural Contêiner (Tabela 1).

Tabela 1 - Referência dos componentes, suas funções e localizações

Componente | Função | Localização
Contêiner (Figura 3) | Principal estrutura do PLUGAR. Responsável por substituir a estrutura dentro da caixa de tomada; interliga todos os demais componentes entre si; fixa e conecta o circuito eletrônico com o componente Módulo. | Fixado dentro da caixa de tomada.
Tampa (Figura 4) | A Tampa além de funcionar como estrutura de design também funciona como fixador do componente Módulo dentro do componente Contêiner e como interruptor geral do PLUGAR. Pode assumir formatos variados para incrementar o design do ambiente. | Encaixado no Contêiner.
Módulo Interruptor (Figura 5) | O Módulo Interruptor contém a funcionalidade de interface humana. Permite que seja feito o acionamento manual de quaisquer funcionalidades programadas no software. | Inserido no Contêiner.

Fonte: Elaborado pelo autor

10

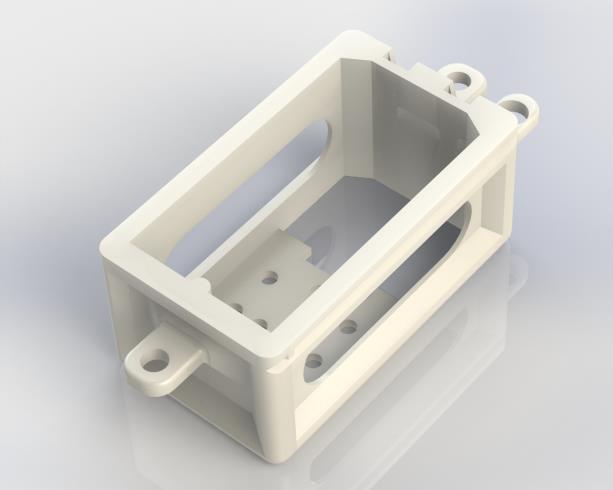
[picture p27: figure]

Figura 3 - Componente Contêiner, versão 4, renderizado Fonte: Imagem do autor

Figura 4 - Componente Tampa, versão 2, renderizado Fonte: Imagem do autor


Figura 5 - Módulo de Interruptor Fonte: Imagem do autor

11

1.4.2 ELETRÔNICA

Do objeto funcional do circuito eletrônico do PLUGAR destaca-se a capacidade de

interligar o microcontrolador ESP8266 versão ESP-201, a cavidade dos módulos e as fontes de

tensão.

O circuito é capaz de converter corrente alternada de alta tensão em corrente contínua

de tensões 5v e 3.3v, redistribuir as faixas de tensões DC e AC para os módulos além de

implementar o barramento I2C para comunicação.

Tabela 2 - Detalhamento dos componentes eletrônicos e suas funções

Nome | Descrição | Características
TSP-12 (Figura 6) | Conversor integrado AC para DC. | • Opera com tensões AC entre 100v e 240v. • Eficiente, perde menos que 0.1W quando em standby. • Fornece 250mA de corrente estavelmente à 12v e aguenta picos de 1A.
L4931 (Figura 7) | Regulador de tensão pacote TO-92. | • Regula tensões com até 2% de tolerância. • Corrente máxima de 300mA com circuito interno limitador de corrente e switch térmico.
Pin Headeres (Figura 8) | Barra de pinos macho-fêmea padrão protoboard. | • Conector de encaixe linear. • Baixo custo.
Terminais parafusados (Figura 9) | Borne integradas com circuito impresso. | • Praticidade • Baixo custo

Fonte: Elaborado pelo autor

12

Figura 6 – TSP-12
Fonte: Imagem (http://www.hlktech.net/product_detail.php?ProId=56) do Autor


Figura 7 – L4931.
Fonte: https://www.adafruit.com/product/2236

Figura 8 – Pin Headeres
Fonte: Imagem (http://www.eletrodex.com.br/barra-conectora-de-pino-estampado-simples-180-2-a-40-pinos.html) do Autor


Figura 9 - Terminais parafusados Fonte: Imagem (http://www.taydaelectronics.com/dg300-screw-terminal-block-2-positions-5mm.html) do Autor

### 2 AMBIENTE DE ESTÁGIO

Guilherme Otávio Ferreira Faria é membro colaborador de uma firma autônoma

prestadora de serviço na área de engenharia e construção civil.

A firma realiza projetos arquitetônicos, projetos elétricos, projetos de prevenção e

combate a incêndio, projetos estruturais e planejamentos e execuções de obras. Presta serviço

para Francisco Imóveis, Martins Empreendimentos, Construtora e Incorporadora Predisul,

Construtora e Incorporadora Premium, dentre outros. Situa-se na Rua Pernambuco, número 50,

bairro Centro da cidade de Divinópolis. Sua missão é executar com maestria obras e projetos

na área de construção civil.


13

Atualmente, buscando expandir a abrangência na prestação de serviço, realizou-se uma

parceria para desenvolver um projeto de automação residencial: o PLUGAR, combinando a

expertise dos serviços realizados pela firma e o conhecimento do aluno aplicado na área de

automação, controle, modelagem, eletrônica e impressão 3D.

O ambiente de estágio conta com estações de qualidade uma vez que na empresa são

utilizados softwares robustos de CAD para o desenvolvimento dos projetos de engenharia civil.

2.1 | ORGANOGRAMA
| De acordo com o ambiente de estágio citado no item 2, foi possível estabelecer um

organograma, no qual apresenta a organização hierárquica da empresa, seus setores e

funcionamentos por meio de cores (Figura 10).

Figura 10 - Organograma da firma. Fonte: Elaborado pelo autor.

14

### 3 ATIVIDADES DESENVOLVIDAS

### 03/04/2017 – Apresentação

Readaptação à metodologia, ambientação e compartilhamento dos recursos necessários para

o desenvolvimento durante o estágio.

### Período de 04/04/2017 a 07/04/2017 – Discussão e detalhamento

Estruturação inicial das etapas necessárias para desenvolvimento do projeto. Observações

sobre a necessidade da readaptação do componente estrutural e da tampa para simplificar o

circuito impresso e a interação no geral. Redesenho do contêiner para suportar apenas um

módulo. Readequação do cronograma do projeto no tempo hábil restante do estágio

supervisionado II e trabalho de conclusão de curso que se seguem entre o primeiro semestre

de 2017 ao segundo semestre de 2017.

15

### Período de 10/04/2017 à 13/04/2017 – Remodelagem da placa de circuito

impresso utilizando as novas definições do projeto.

Readaptação das bibliotecas de apoio para o diagrama e placa de circuito impresso dentro do

Eagle; referentes ao conector dos módulos (Figura 11 e Figura 12).


Figura 11 - Esquemática do conector de módulo Fonte: Imagem do autor


Figura 12 - Pacote do conector de módulos Fonte: Imagem do autor

16

Integração dos componentes escolhidos no circuito esquematizado (Figura 13) com base nas

medidas pré-estabelecidas (Figura 14). Modelagem da placa de circuito impresso (Figura 15).


Figura 13 - Esquema eletrônico readaptado com apenas um conector. Fonte: Imagem do autor


Figura 14 - Padrão restabelecido. Versão 4. Fonte: Imagem do autor


Figura 15 – Placa de circuito impresso (versão 4) do PLUGAR. Fonte: Imagem do autor

17

### Período de 17/04/2017 à 18/04/2017 – Readaptação dos componentes

Contêiner e Tampa.

Introdução a quarta versão do Contêiner (Figura 16 e Figura 17) para adequar as necessidades

de acomodação de apenas um módulo, diferentemente das versões anteriores que acomodara

até dois módulos. Remodelagem do componente Tampa (Figura 18 e Figura 19) para adequar

ao novo Contêiner.


Figura 16 - Contêiner renderizado. Versão 4. Vista ortogonal.


Fonte: Imagem do Autor. | Figura 17 - Contêiner impresso em 3D. Versão 4. Vista ortogonal. Fonte: Imagem do Autor.


Figura 18 - Tampa renderizado. Versão 2. Vista ortogonal. Fonte: Imagem do Autor.


Figura 19 - Tampa impressa em 3D. Versão 2. Vista ortogonal. Fonte: Imagem do Autor.

18

### Período de 19/04/2017 à 20/04/2017 – Componente Módulo Base e Módulo

### Interruptor

Com base no modelo eletrônico e o desenho técnico do padrão estabelecido, foi desenvolvido

o componente estrutural Módulo Base (Figura 20) contemplando as métricas das conexões

com o circuito principal e o encaixe geral previsto pelo componente Tampa. A partir do

mesmo, fora desenhado o primeiro módulo funcional do projeto, o Módulo Interruptor

(Figura 21).

Figura 20 - Componente Módulo Base, primeira versão. Fonte: Imagem do autor.

Figura 21 – Componente Módulo Interruptor, primeira versão. Fonte: Imagem do autor.

19

### Período de 24/04/2017 à 25/04/2017 – Circuito impresso do componente

### Módulo Interruptor

O circuito do Módulo de Interruptor conta com um terminal parafusado para conexão do

interruptor via cabo, pinagem padrão do módulo do PLUGAR e pinagem do CI I2C PFC8574

(Figura 22 e Figura 23).


Figura 22 – Esquemática do circuito impresso do Módulo Interruptor no CAD Eagle.
Fonte: Imagem do autor


Figura 23 – Placa de circuito impresso do Módulo Interruptor no CAD Eagle.
Fonte: Imagem do autor

20

### Período de 26/04/2017 a 28/04/2017 – Planejamento de fabricação de circuitos

utilizando Router CNC.

Para o planejamento dos circuitos impressos fora utilizado software CAD Eagle (Figura 24).

A router CNC na qual foram desenvolvidas as placas é a Cyclone PCB Factory (Figura 26).

Também foi utilizado o software livre OpenCNCPilot (Figura 25) para converter o desenho

CAD em gcode.


Figura 24 – Software CAD Eagle. Fonte: Imagem do autor

Figura 25 – Software OpenCNCPilot com o circuito do PLUGAR. Fonte: Imagem do Autor.


Figura 26 – Router CNC Cyclone PCB Factory. Fonte: Imagem do autor

21

### Período de 02/05/2017 à 08/05/2017 – Fabricação dos circuitos impressos

Utilizando o software OpenCNCPilot gerou-se duas revisões de códigos gcode os quais

foram utilizados pela Cyclone PCB Factory (Figura 27). Os resultados destas versões (Figura

28 e Figura 30) não foram muito satisfatórios causando um imprevisto na execução do projeto

(Figura 29).


Figura 27 – Router CNC Cyclone PCB Factory fresando a peça. Fonte: Imagem do autor.


Figura 28 – Resultado da primeira tentativa de frezagem. Fonte: Imagem do autor.

Figura 29 – Conferencia dos componentes na segunda frezagem. Fonte: Imagem do autor.

Figura 30 – Resultado da segunda tentativa de frezagem. Fonte: Imagem do autor.

22

### Período de 09/05/2017 à 10/05/2017 – Pré-montagem e análise do final da segunda etapa do projeto

Com base nas versões previamente estabelecidas, fora testado o atendimento dos objetivos

requeridos. O encaixe do componente Contêiner para o componente Tampa está funcional,

contando com travas que cumpriram sua função (Figura 31); métrica do componente Tampa

ficou dentro dos padrões atuais (Figura 32); novo padrão de selagem do módulo ficou correto,

com uma folga tolerável (Figura 33 e Figura 34).


Figura 31 - Encaixe da Tampa no Contêiner. Fonte: Imagem do autor


Figura 32 – Comparativo da Tampa com uma tomada. Fonte: Imagem do autor


Figura 33 – Novo padrão de selagem, aberto. Fonte: Imagem do autor.

Figura 34 – Novo padrão de selagem, fechado. Fonte: Imagem do autor.

23

### 4 DISCUSSÕES GERAIS

Com a popularização dos movimentos Maker pelo mundo, a difusão da tecnologia open-

source reflete em qualificação técnica informal e gratuita. Gera uma cadeia de consequências,

desde novas ideias, novos produtos até novos padrões de mercado na própria comunidade.

Grandes contribuições do mundo Maker devem ser citadas aqui pois são cruciais para o projeto

PLUGAR. Os padrões de componentes de impressora 3D possibilitaram a montagem da

impressora 3D Graber i3 utilizada no estágio. Com a ajuda deste recurso foi possível expandir

o projeto para o meio físico, testando iterações dos modelos até encontrar os resultados

desejados. Utilizando os recursos de impressão 3D, fora construída a CNC router Cyclone PCB

Factory, que também é um projeto aberto e grátis.

4.1 | DO PROJETO
| O PLUGAR evoluiu neste estágio, mais uma vez, abrindo mão de um slot modular. Este

passo foi importante para a concretização do espaço interno do projeto que é concorrido pela

complexidade de manufatura; simples a que dispomos. Ainda conta com um grande caminho a

percorrer quanto a implementação do sistema de controle e montagem dos componentes.

| Os recursos utilizados no projeto proveram tanto da empresa quanto do aluno. Os

softwares pagos como Eagle e Solidworks foram utilizados na empresa por serem licenciados

para uso doméstico e comercial. Os softwares livres tais como Repetier Host, Slic3r,

Meshmixer, Blender e OpenCNCPilot, foram utilizados pelo aluno. A impressora 3D e a router

CNC são de propriedade do aluno, porém todo design e prototipagem foram feitos sob

supervisão do engenheiro para avaliação do atendimento dos requisitos.

4.2 DO AMBIENTE DE ESTÁGIO

Sendo amigos de longa data, o relacionamento entre supervisor e aluno se mostrou

simplificado, divertido e direto. A troca de informações, conhecimento e opiniões é suavizada

pela familiaridade com o companheiro de serviço tanto no momento de delegar funções quanto

no momento de buscar ajuda.

24

Mesmo atarefado constantemente em projetos paralelos o supervisor do estágio soube

repassar e avaliar as atividades no momento necessário e assegurou o cumprimento do

cronograma estabelecido.

### 5 CONSIDERAÇÕES FINAIS

Inspirado em novas vertentes do setor de tecnologia, o projeto PLUGAR se mostrou

como um desafio, bem como, excelente ponto de iniciação no mercado profissional, embasando

novas áreas além da capacitação curricular do aluno e expandindo a área de interesse e atuação

do mesmo. Participar, desenvolver e criar, desde o conceito até a realidade, foram metodologias

de trabalho gratificantes e, de certa forma, pioneiras.

Por meio do estágio supervisionado, que se finaliza através do relatório, foi possível

alcançar um aprendizado extracurricular além de instigar e fomentar o estudo e interesse em

diferentes áreas ímpares às comuns.

### 6 REFERÊNCIAS

ALLDATASHEET, L4931 – Very Low Dropout Voltage Regulator, Datasheet (PDF) –

STMicroeletronics. Disponível em

<http://pdf1.alldatasheet.com/datasheet-

pdf/view/22466/STMICROELECTRONICS/L4931.html>. (http://pdf1.alldatasheet.com/datasheet-pdf/view/22466/STMICROELECTRONICS/L4931.html) Acesso em 26 de setembro de

2016.

CAMARA, Rômulo. Barramento e Protocolo I2C. Juazeiro, BA: Univasf. 2013. p. 1-3.

Disponível em:

<http://www.univasf.edu.br/~romulo.camara/novo/wp-content/uploads/2013/11/Barramento-

e-Protocolo-I2C.pdf>. (http://www.univasf.edu.br/~romulo.camara/novo/wp-content/uploads/2013/11/Barramento-e-Protocolo-I2C.pdf) Acesso em 28 de novembro de 2016.

25

DENARDIN, Gustavo Weber. Microcontroladores. Joinville, SC: Udesc. [2005], p. 1-34.

Disponível em:

<http://www.joinville.udesc.br/portal/professores/eduardo_henrique/materiais/apostila_micro

_do_Gustavo_Weber.pdf>. (http://www.joinville.udesc.br/portal/professores/eduardo_henrique/materiais/apostila_micro_do_Gustavo_Weber.pdf) Acesso em 28 de novembro de 2016.

ESPRESSIF, ESP8266EX. Disponível em:

<https://espressif.com/en/products/hardware/esp8266ex/overview>. Acesso em 19 de setembro

de 2016.

ESP8266, Community Forum. Disponível em <http://www.esp8266.com/>. Acesso em 19 de

setembro de 2016.

MESHMIXER: GENERATE SUPPORTS. Disponível em:

<http://www.instructables.com/id/Meshmixer-Generate-Supports/>. Acesso em 11 de outubro

de 2016.

SILVA, Tarcisio. Introdução ao CadSoft Eagle. 2016.

Disponível em: <https://www.embarcados.com.br/tutorial-eagle-introducao/>. Acesso em 22

de setembro de 2016.

TEXAS INSTRUMENTS, PCF8574 Remote 8-Bit I/O Expander for I2C Bus. 2015. Disponível

em: <http://www.ti.com/lit/ds/symlink/pcf8574.pdf>. Acesso em 26 de setembro de 2016.

JARAGUACNC, O Que é Router CNC. Disponível em: <http://jaraguacnc.com.br/o-que-e-

router-cnc.html>. (http://jaraguacnc.com.br/o-que-e-router-cnc.html) Acesso em 04 de abril de 2017.

OpenCNCPilot, OpenCNCPilot is a GRBL compatible G-Code Sender. Disponível em:

<https://github.com/martin2250/OpenCNCPilot>. Acesso em 05 de abril de 2017.

Cyclone PCB Factory, Cyclone (Circuit Cloner) is a CNC mill intended for PCB

manufacturing. Disponível em: <https://github.com/CarlosGS/Cyclone-PCB-Factory>. Acesso

em 04 de abril de 2017.

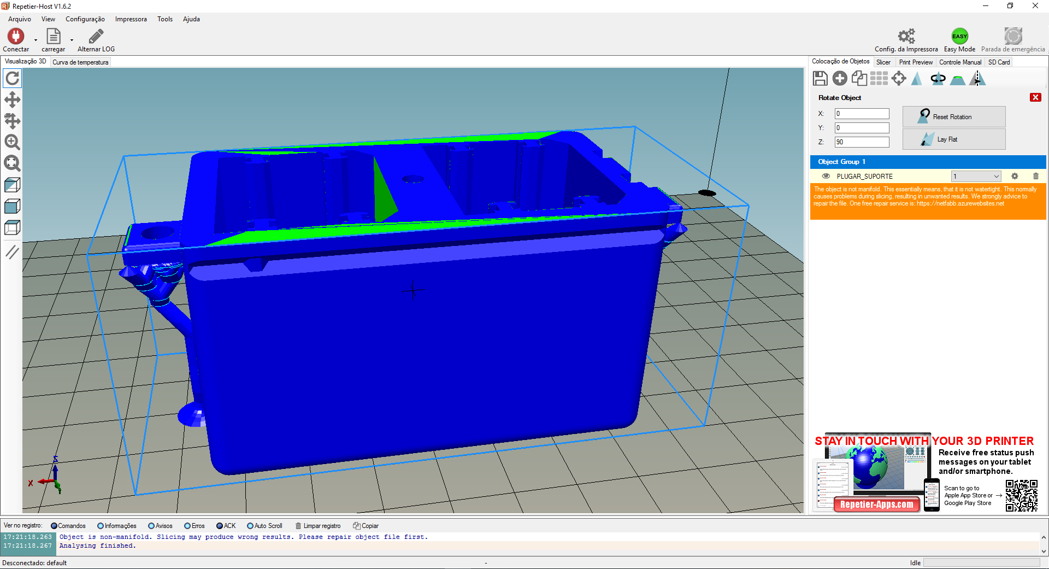
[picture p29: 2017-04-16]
Estágio 1/Fotos/Conteiner - 1a versao.PNG

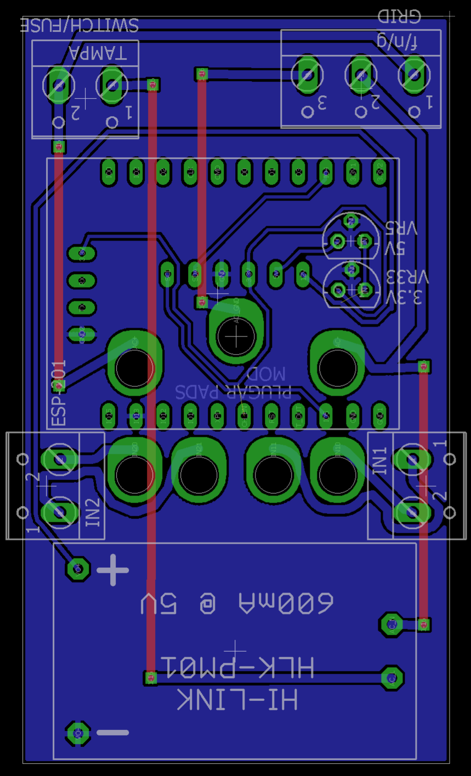
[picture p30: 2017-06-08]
Estágio 2/Fotos/Placa principal.somente.png

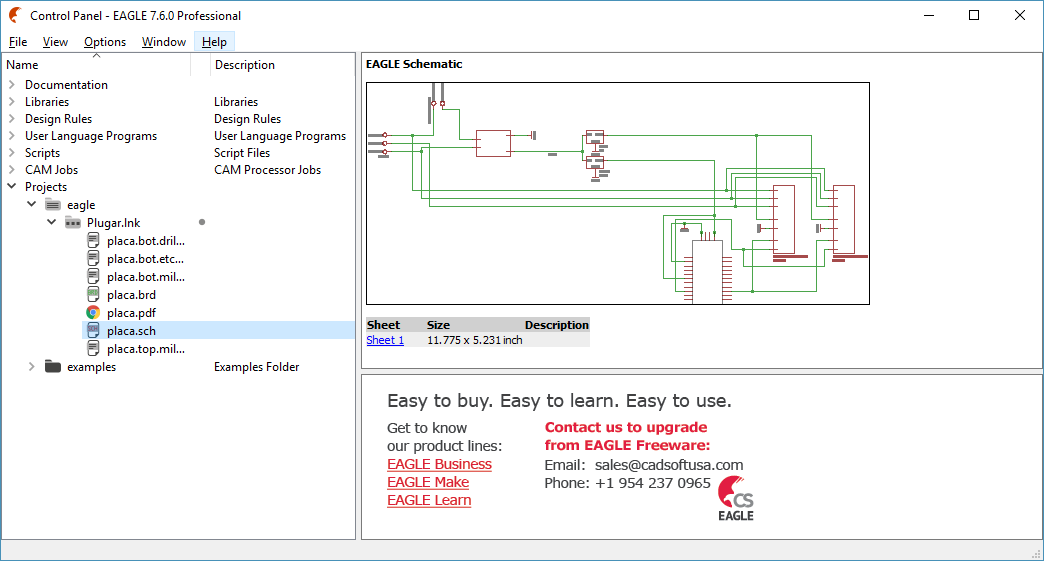
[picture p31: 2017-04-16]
Estágio 2/Fotos/Eagle.PNG

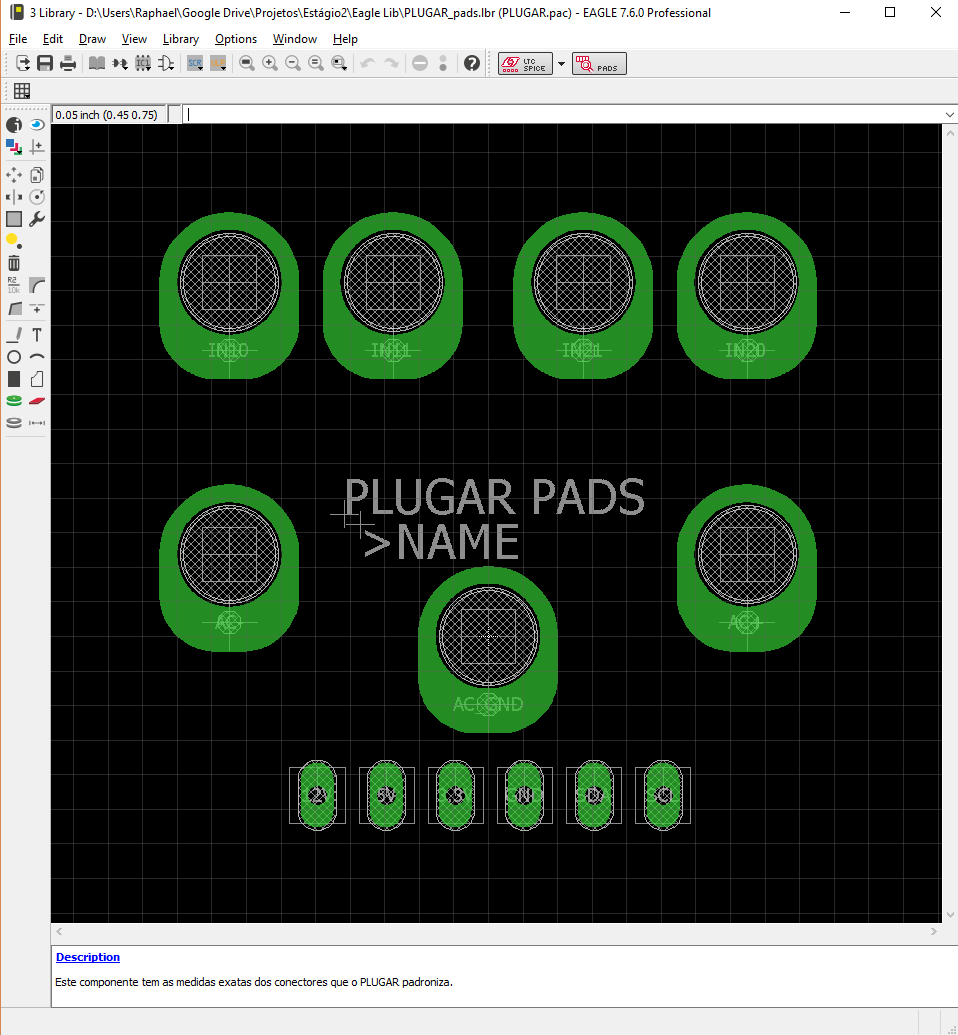
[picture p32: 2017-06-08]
Estágio 2/Fotos/Eagle Lib - MODULOPAD - package.png

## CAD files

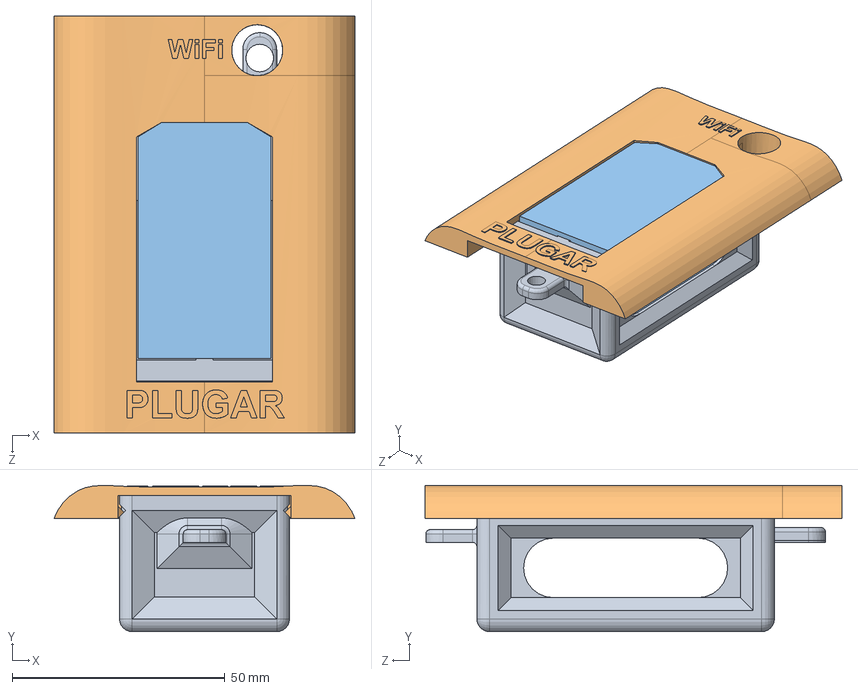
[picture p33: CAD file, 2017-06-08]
Estágio 2/3D/Montagem.SLDASM
70.8 x 34.4 x 98.0 mm
PLUGAR
TAMPA.v2
MODULO

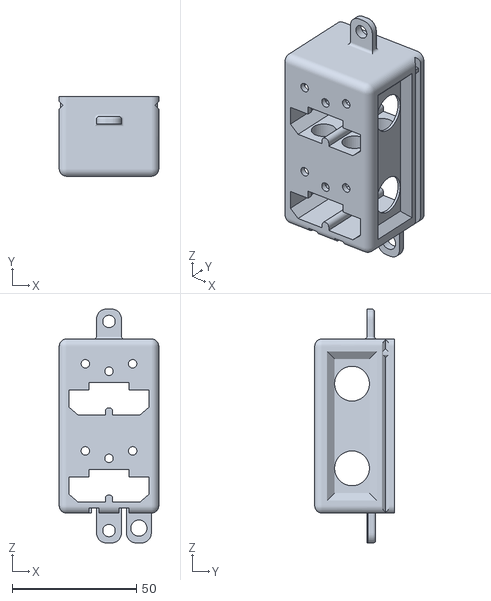
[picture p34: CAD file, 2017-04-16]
Estágio 1/3D/PLUGAR.STL
40.0 x 32.0 x 94.0

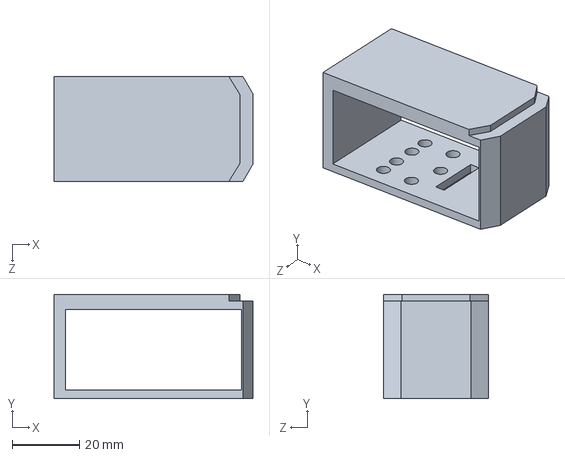
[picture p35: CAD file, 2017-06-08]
Estágio 2/3D/MODULO_INTERRUPTOR.SLDPRT
59.3 x 31.0 x 31.3 mm

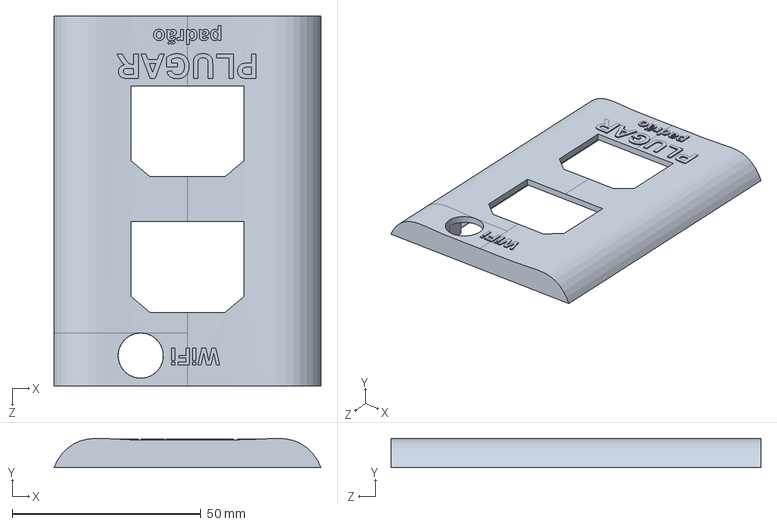
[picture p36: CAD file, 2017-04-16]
Estágio 1/3D/TAMPA.SLDPRT
70.8 x 7.79 x 98.0 mm

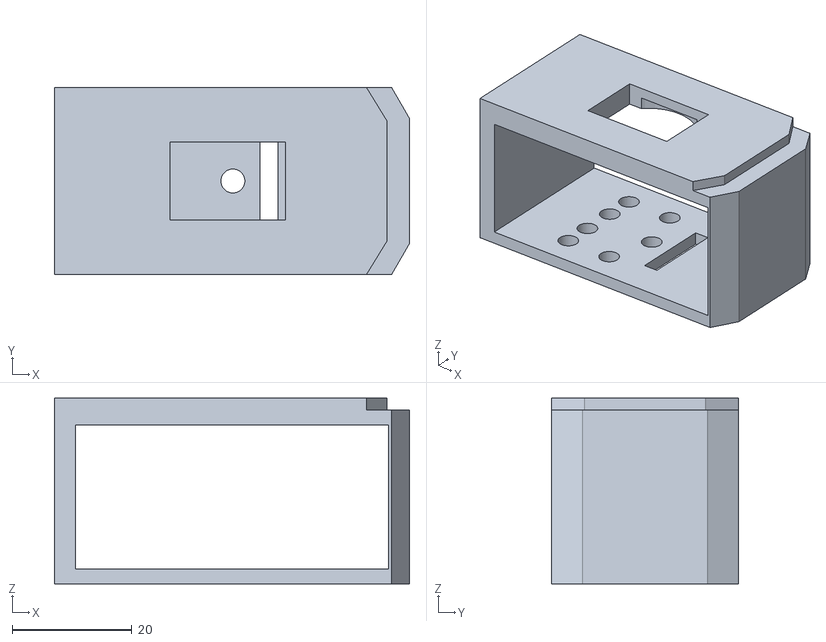
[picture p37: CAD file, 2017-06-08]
Estágio 2/3D/MODULO_INTERRUPTOR.v1.STL
59.3 x 31.3 x 31.0

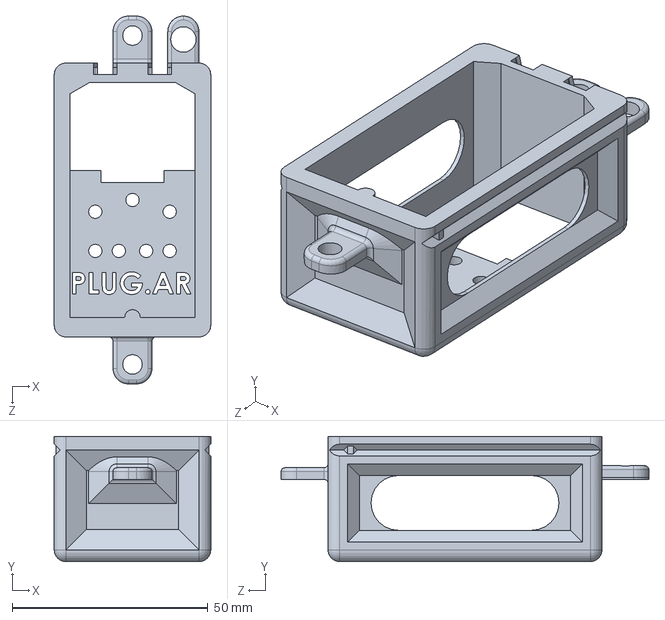
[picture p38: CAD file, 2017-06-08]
Estágio 2/3D/PLUGAR.SLDPRT
40.0 x 32.0 x 94.0 mm

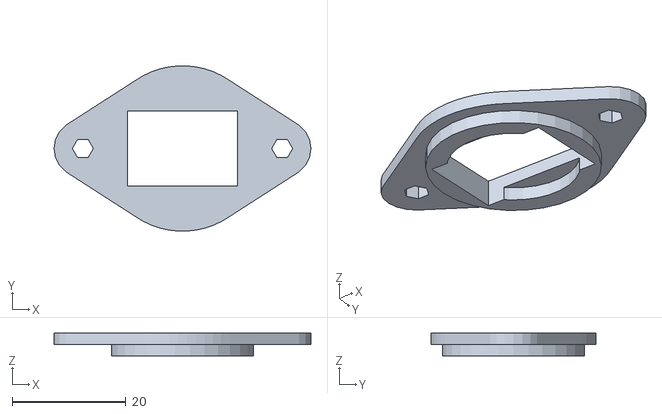
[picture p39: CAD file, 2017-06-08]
Estágio 2/3D/MODULO_INTERRUPTOR_SWITCH.stl
45.1 x 29.0 x 4.00

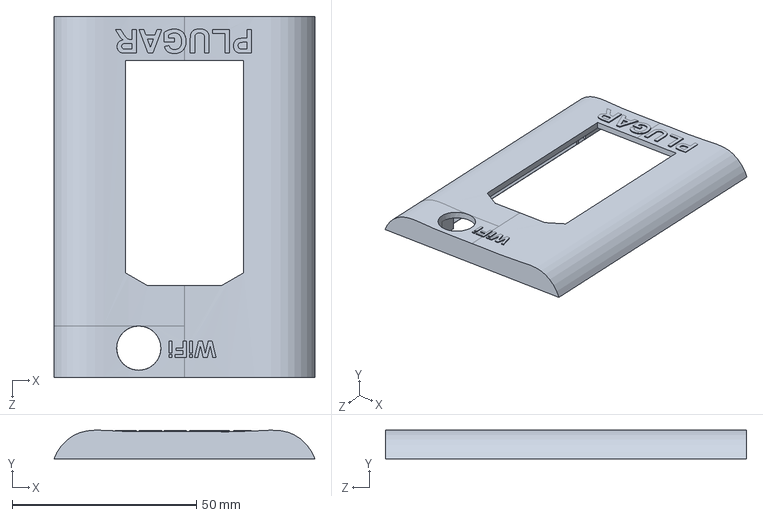
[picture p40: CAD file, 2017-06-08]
Estágio 2/3D/TAMPA.v2.SLDPRT
70.8 x 7.79 x 98.0 mm

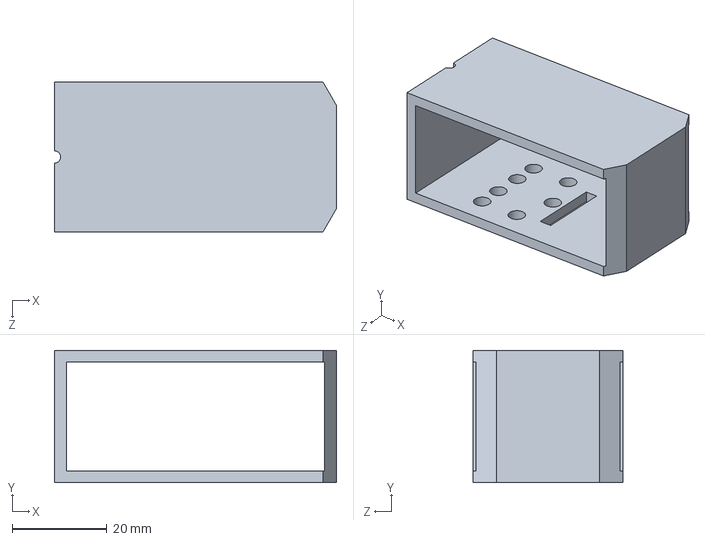
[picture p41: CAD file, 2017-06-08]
Estágio 2/3D/MOD-INT+TOMADA.SLDPRT
59.6 x 28.0 x 31.6 mm

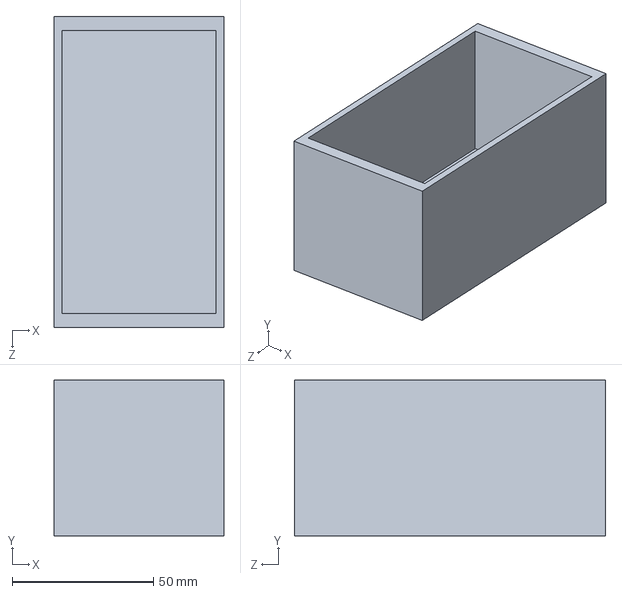
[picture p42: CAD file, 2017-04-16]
Estágio 2/3D/Caixa.SLDPRT
60.0 x 55.0 x 110.0 mm

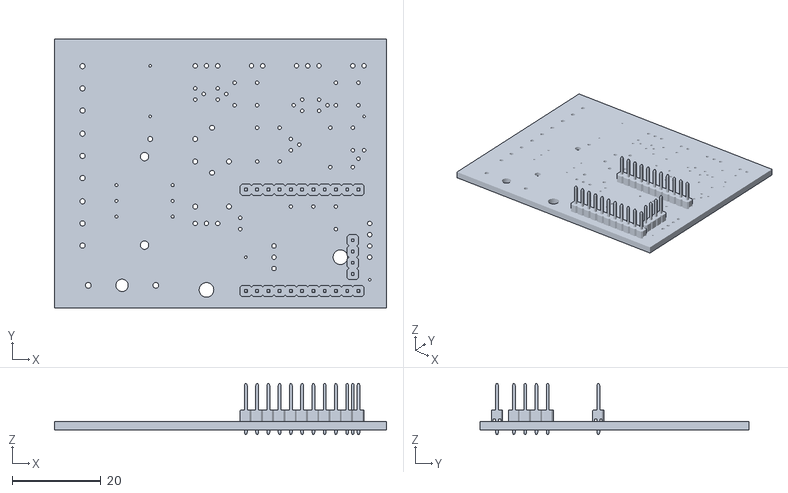
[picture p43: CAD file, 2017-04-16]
Estágio 2/3D/placa.stl
74.9 x 60.6 x 11.5

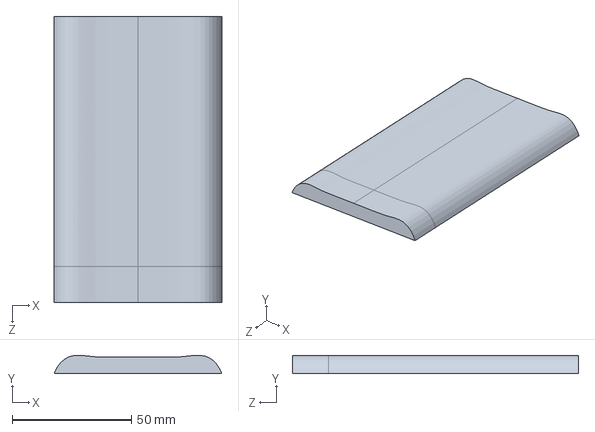
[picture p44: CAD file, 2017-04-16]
Estágio 2/3D/TAMPA_DESLIGADO.SLDPRT
70.4 x 7.71 x 120.0 mm

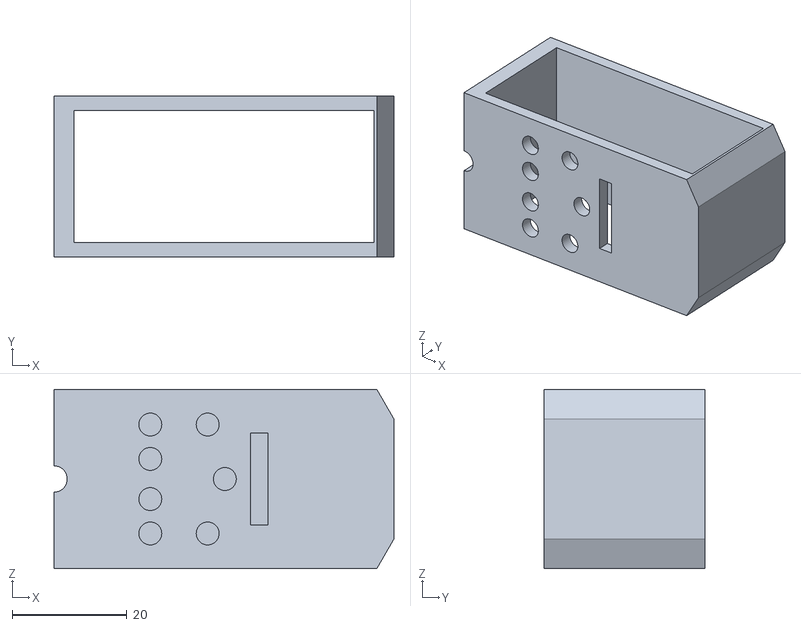
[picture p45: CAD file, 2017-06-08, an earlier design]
Estágio 2/3D/MODULO.v2.STL
59.3 x 28.0 x 31.3

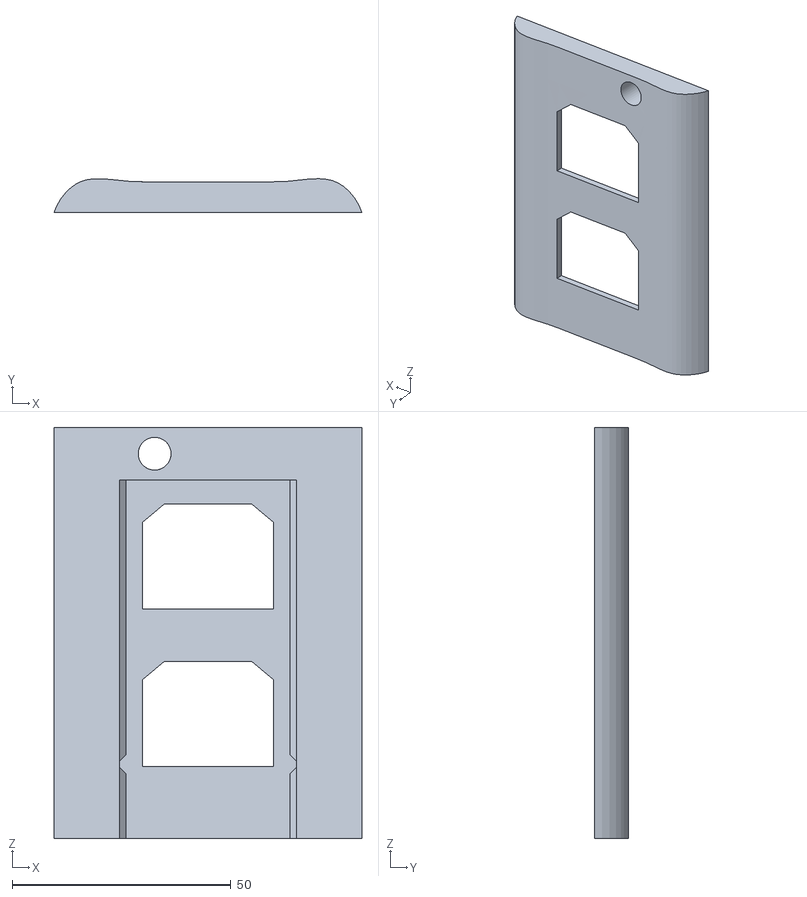
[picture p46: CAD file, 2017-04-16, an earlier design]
Estágio 2/3D/TAMPA.STL
70.4 x 7.71 x 94.0

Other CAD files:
Estágio 2/3D/PLUGAR_V2.STL
Estágio 2/3D/TAMPA.v3.STL
Estágio 2/3D/MODULO.v3.STL
Estágio 2/3D/MODULO.SLDPRT
Estágio 2/3D/Caixa.STL
Estágio 2/3D/MODULO.STL
Estágio 2/3D/MODULO_INTERRUPTOR.STL
Estágio 2/3D/PLUGAR.SLDDRW
Estágio 2/3D/TAMPA.v2.STL
Estágio 2/3D/TAMPA_v2.STL
Estágio 2/3D/montagem.blend

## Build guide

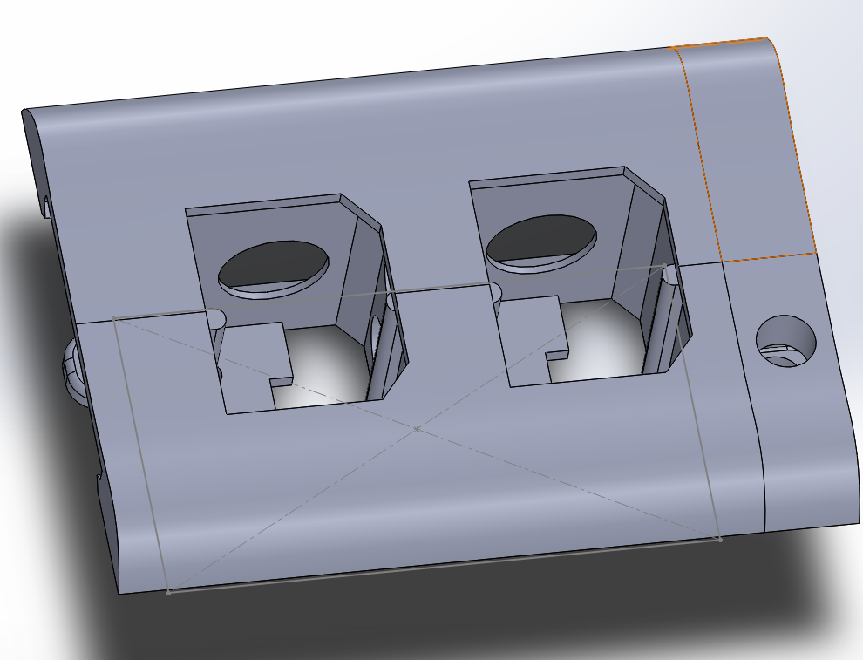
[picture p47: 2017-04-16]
Estágio 1/Fotos/Montagem com tampa - 2.PNG

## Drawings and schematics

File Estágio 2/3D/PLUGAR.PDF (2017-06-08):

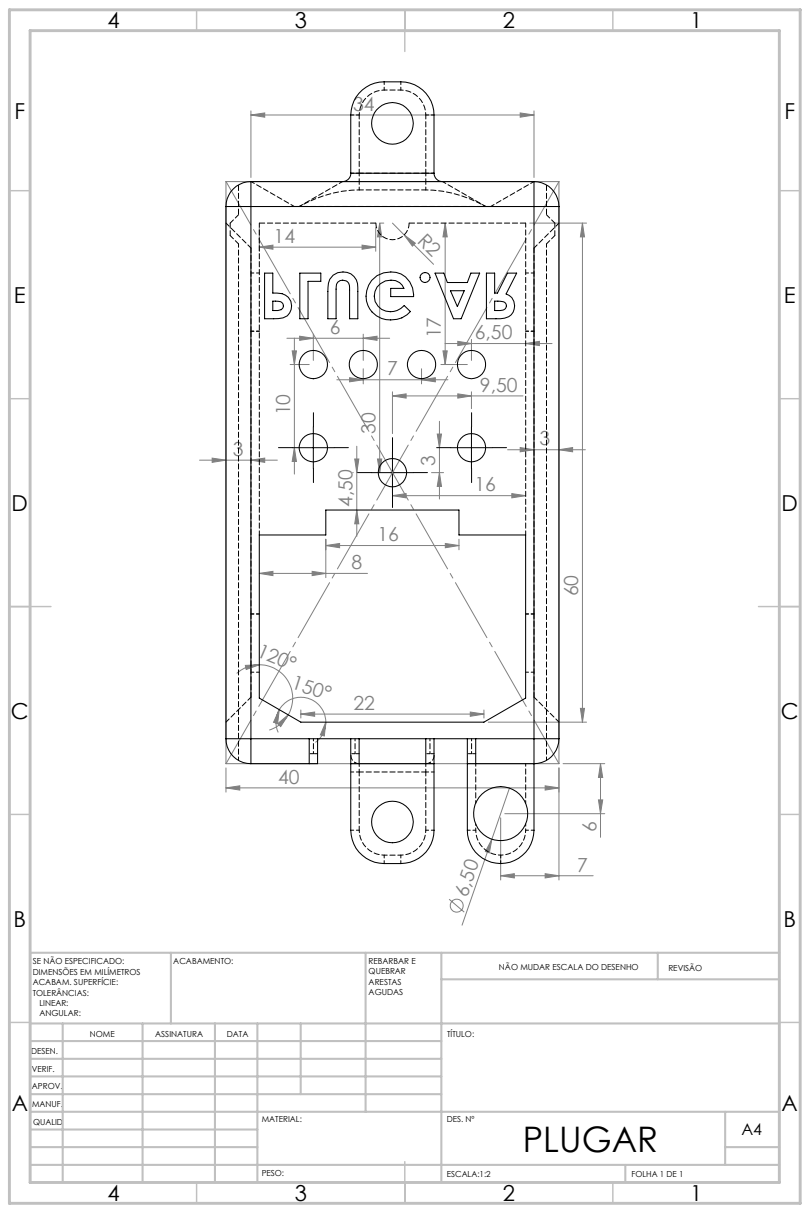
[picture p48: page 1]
ACABAMENTO:; REBARBAR E; NÃO MUDAR ESCALA DO DESENHO; REVISÃO; ESCALA:1:2; FOLHA 1 DE 1

SE NÃO ESPECIFICADO:
DIMENSÕES EM MILÍMETROS
ACABAM. SUPERFÍCIE:
TOLERÂNCIAS:
LINEAR:
ANGULAR:

NOME | ASSINATURA | DATA | | | | TÍTULO:

DESEN.
VERIF.
APROV.
MANUF.
QUALID | | | | MATERIAL: | DES. Nº PLUGAR | A4

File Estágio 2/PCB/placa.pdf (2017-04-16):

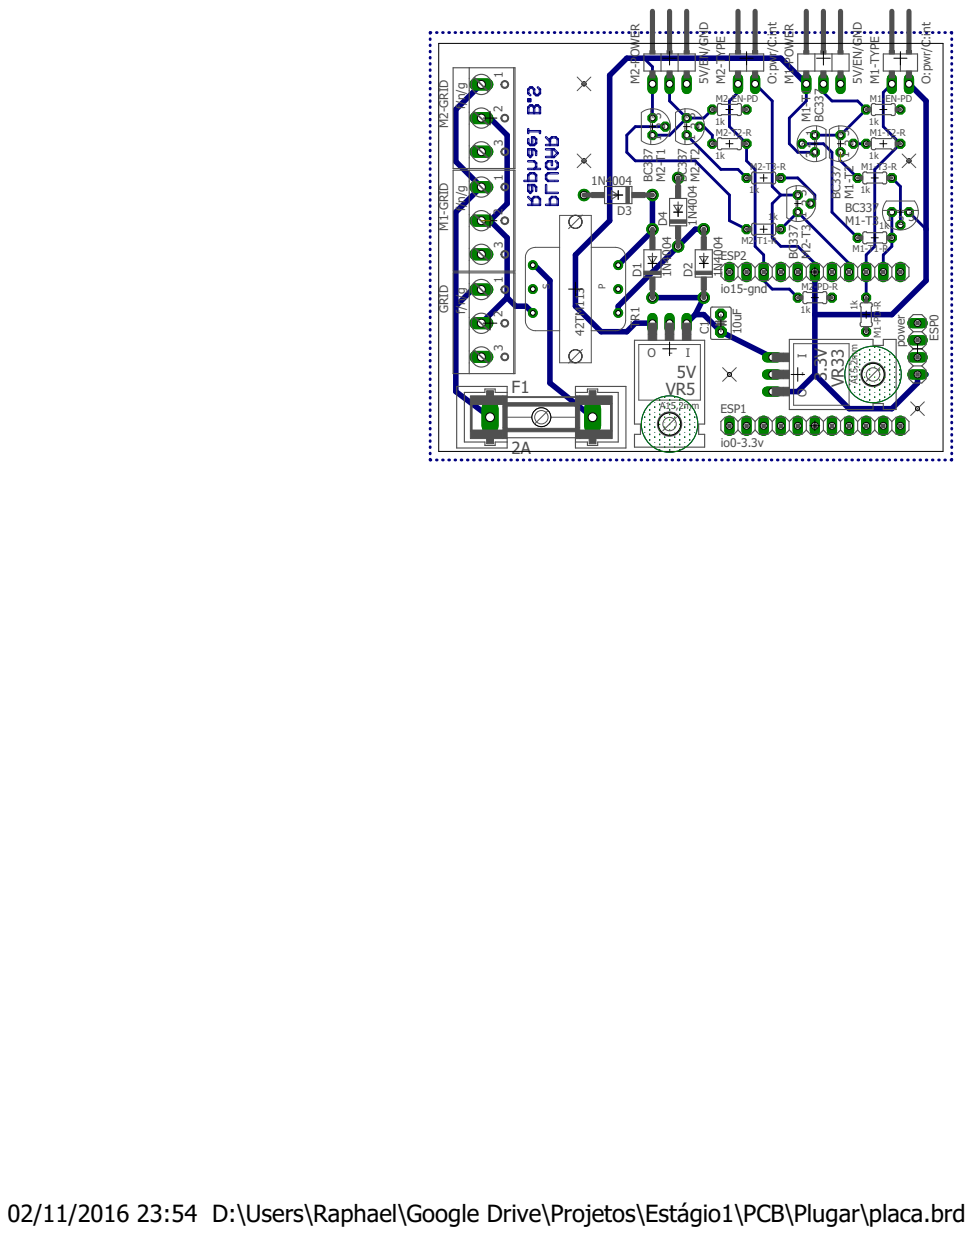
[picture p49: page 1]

5V/EN/GND O:pwr/C:int 1k

02/11/2016 23:54 D:\Users\Raphael\Google Drive\Projetos\Estágio1\PCB\Plugar\placa.brd

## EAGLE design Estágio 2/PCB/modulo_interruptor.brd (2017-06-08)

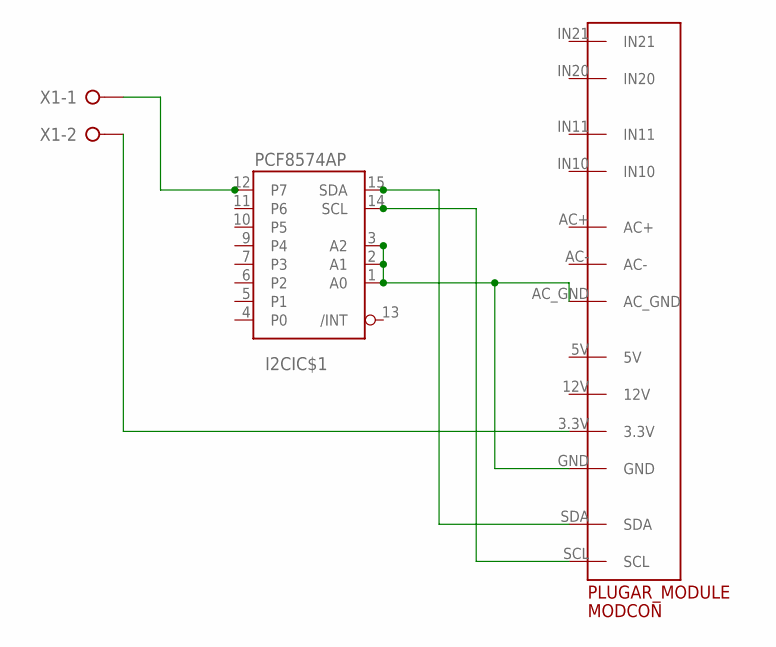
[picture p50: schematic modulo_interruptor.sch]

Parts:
I2C: PCF8574AP; DIL16
MODCON: PLUGARPADS; PLUGAR
X1: W237-02P; W237-132

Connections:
GND: I2C.1 (A0), I2C.2 (A1), I2C.3 (A2), I2C.8 (GND), MODCON.AC_GND, MODCON.GND
unnamed: MODCON.3.3V, X1.2
unnamed: I2C.12 (P7), X1.1
unnamed: I2C.14 (SCL), MODCON.SCL
unnamed: I2C.15 (SDA), MODCON.SDA
VCC: I2C.16 (VCC)

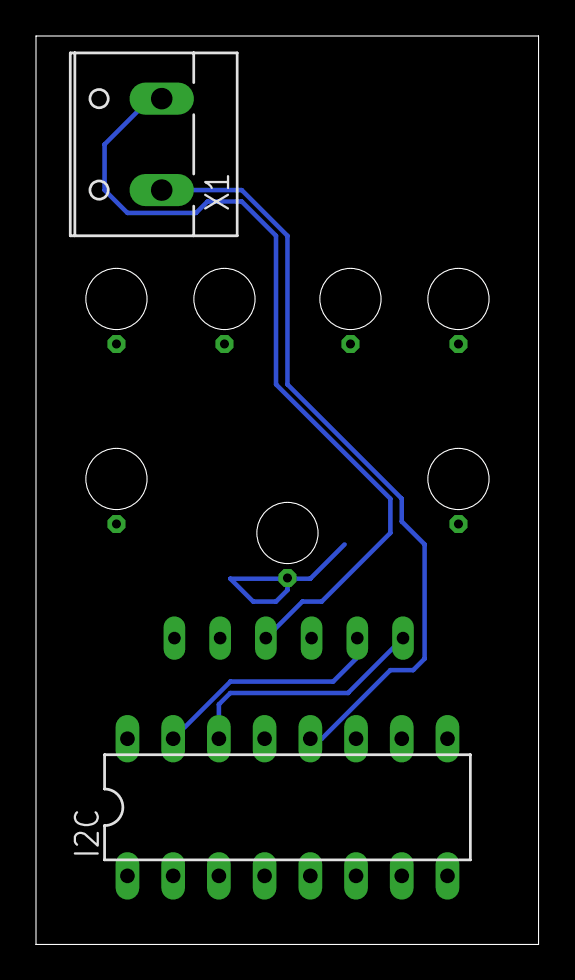
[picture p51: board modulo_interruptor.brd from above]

Board: 2 copper layers, 27.9 x 50.5 mm, 3 parts (0 on the bottom side), 5 nets.

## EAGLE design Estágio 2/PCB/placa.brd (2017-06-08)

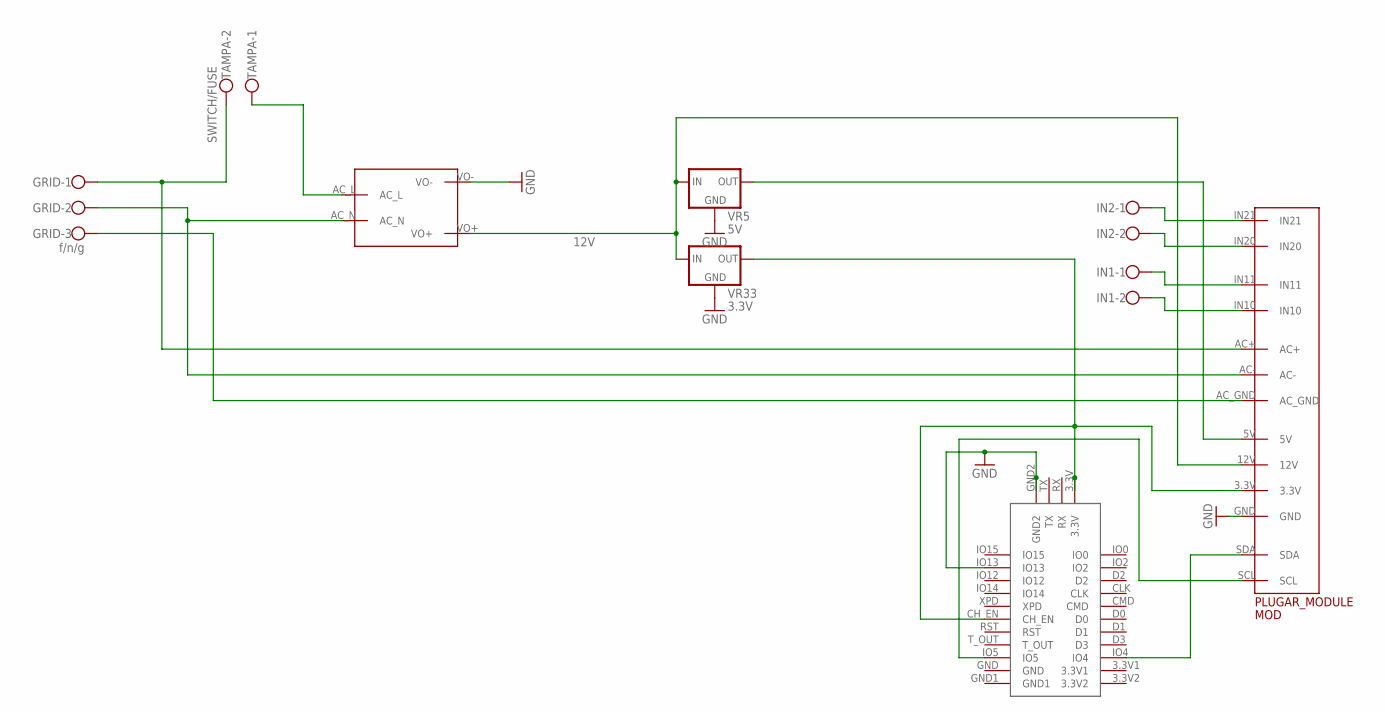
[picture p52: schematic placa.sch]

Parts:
GRID: f/n/g; W237-103
IN1, IN2: W237-102
MOD: PLUGARPADS; PLUGAR
TAMPA: SWITCH/FUSE; W237-102
U$1: MAINS_CONVERTERS; HLK-PM01
U$2: ESP-201
VR5: 5V; 78LXX
VR33: 3.3V; 78LXX

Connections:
3.3V: MOD.3.3V, U$2.3.3V, U$2.CH_EN, VR33.OUT
5V: MOD.5V, VR5.OUT
12V: MOD.12V, U$1.VO+, VR5.IN, VR33.IN
AC+: GRID.1, MOD.AC+, TAMPA.2
AC-: GRID.2, MOD.AC-, U$1.AC_N
AC_GND: GRID.3, MOD.AC_GND
GND: MOD.GND, U$1.VO-, U$2.GND2, U$2.IO13, VR5.GND, VR33.GND
unnamed: IN2.1, MOD.IN21
unnamed: TAMPA.1, U$1.AC_L
unnamed: IN2.2, MOD.IN20
unnamed: IN1.1, MOD.IN11
unnamed: IN1.2, MOD.IN10
SCL: MOD.SCL, U$2.IO5
SDA: MOD.SDA, U$2.IO4

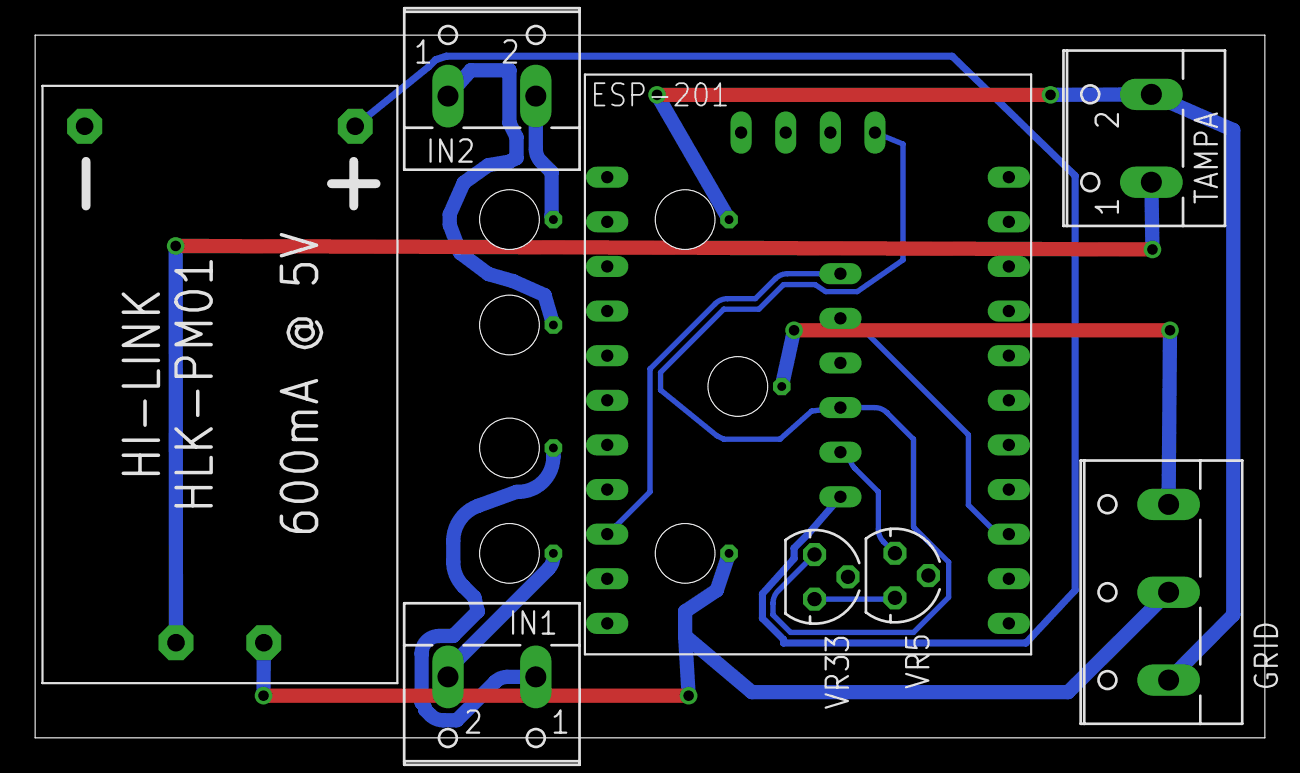
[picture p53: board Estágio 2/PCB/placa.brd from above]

Board: 2 copper layers, 70.0 x 40.0 mm, 9 parts (0 on the bottom side), 14 nets.

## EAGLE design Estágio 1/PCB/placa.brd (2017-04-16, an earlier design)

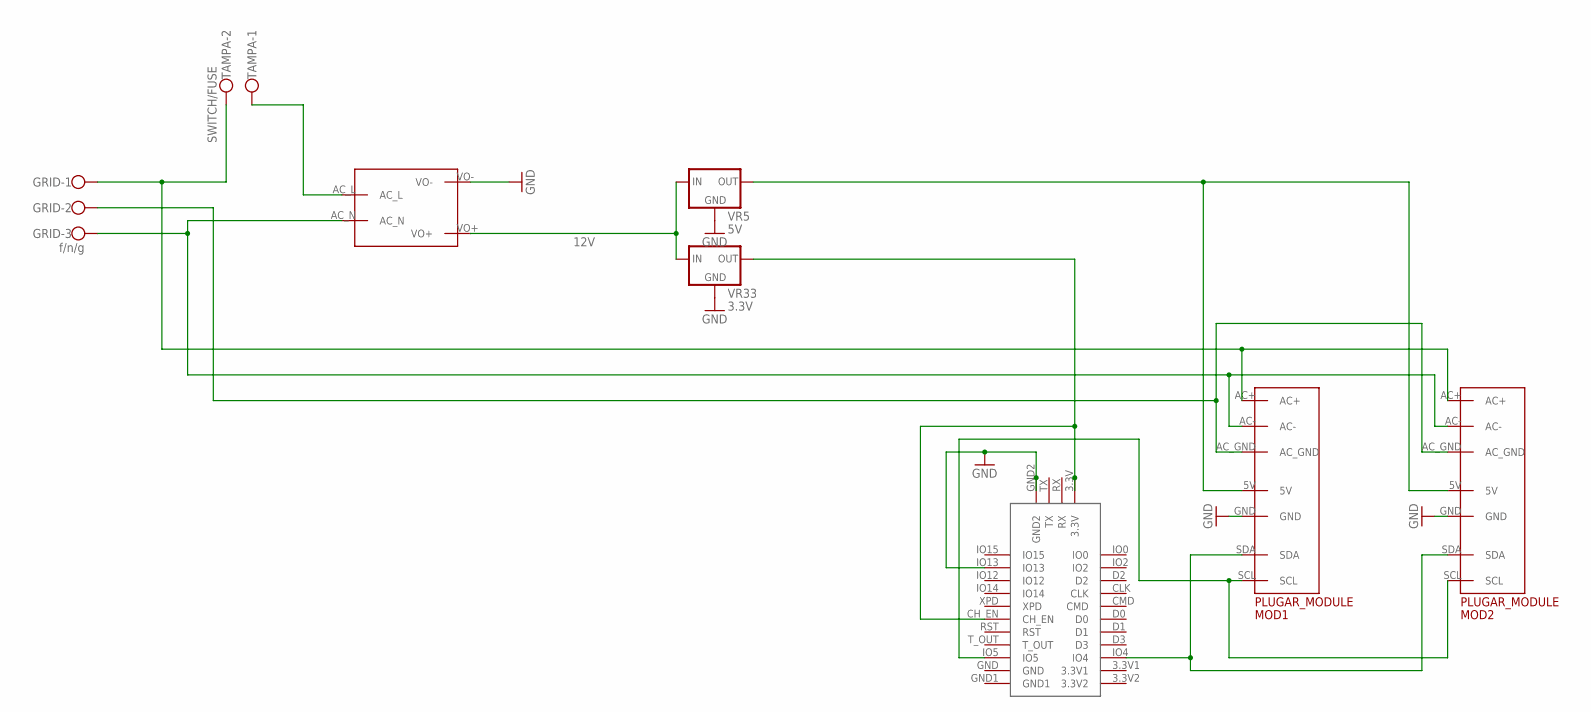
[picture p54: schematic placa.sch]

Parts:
GRID: f/n/g; W237-103
MOD1, MOD2: PLUGARPADS; PLUGAR
TAMPA: SWITCH/FUSE; W237-102
U$1: MAINS_CONVERTERS; HLK-PM01
U$2: ESP-201
VR5: 5V; 78LXX
VR33: 3.3V; 78LXX

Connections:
3.3V: U$2.3.3V, U$2.CH_EN, VR33.OUT
5V: MOD1.5V, MOD2.5V, VR5.OUT
12V: U$1.VO+, VR5.IN, VR33.IN
AC+: GRID.1, MOD1.AC+, MOD2.AC+, TAMPA.2
AC-: GRID.3, MOD1.AC-, MOD2.AC-, U$1.AC_N
AC_GND: GRID.2, MOD1.AC_GND, MOD2.AC_GND
GND: MOD1.GND, MOD2.GND, U$1.VO-, U$2.GND2, U$2.IO13, VR5.GND, VR33.GND
unnamed: TAMPA.1, U$1.AC_L
SCL: MOD1.SCL, MOD2.SCL, U$2.IO5
SDA: MOD1.SDA, MOD2.SDA, U$2.IO4

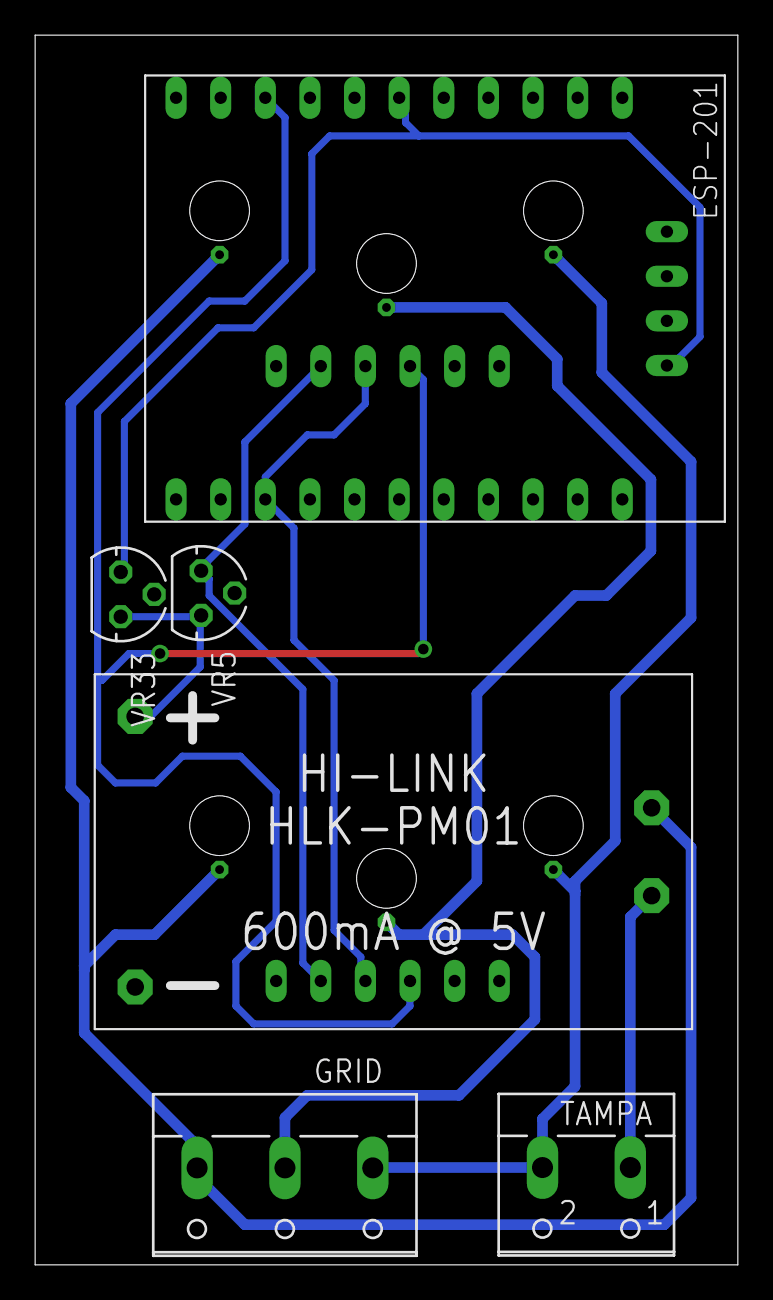
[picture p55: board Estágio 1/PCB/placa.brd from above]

Board: 2 copper layers, 40.0 x 70.0 mm, 8 parts (0 on the bottom side), 10 nets.

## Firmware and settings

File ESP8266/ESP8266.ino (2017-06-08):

#include "WiFinder.h"
#include <FirebaseArduino.h>

#define FIREBASE_HOST "YOUR_FIREBASE_HOST.firebaseio.com"
#define FIREBASE_AUTH "YOUR_FIREBASE_AUTH"
#define LED_PIN 10
#define BTN_PIN 2

char* WIFIS[][2] = {
  {"Wifi1", "wifi1pass"},
  {"Wifi2", "wifi2pass"}
};
WiFinder wifinder(WIFIS);

volatile bool led_status, alterado = false;
volatile int fb_delay = 1000, prev_delay = 1000;

StaticJsonBuffer<50> tsoBuffer;
JsonObject& timeStampObject = tsoBuffer.createObject();

StaticJsonBuffer<250> nodemcuBuffer;
JsonObject& nodemcuObject = nodemcuBuffer.createObject();

void setup() {
  Serial.begin(115200);
  wifinder.setLed(LED_PIN);
  wifinder.connect();
  pinMode(BTN_PIN, INPUT_PULLUP);
  Firebase.begin(FIREBASE_HOST, FIREBASE_AUTH);
  Firebase.setString("localIp", wifinder.getLocalIp());
  attachInterrupt(BTN_PIN, readBtn, FALLING);
  initJSONs();
}

void loop() {
  wifinder.handle();
  readLEDFirebase();
  updateFirebase();
  readDelayFirebase();

  delay(fb_delay);
}

// Inicializa conteudo statico dos jsons
void initJSONs(){
  timeStampObject[".sv"] = "timestamp";
  nodemcuObject["photoURL"] = "https://cknodemcu.files.wordpress.com/2015/10/nodemcu2.png?w=150";
  nodemcuObject["displayName"] = "NodeMCU";
  nodemcuObject["date"] = timeStampObject;
}

// Lê do firebase: LED
void readLEDFirebase(){
  bool cled_status = Firebase.getBool("LED");
  if(led_status == cled_status) return;
  led_status = cled_status;
  Serial.print("LED alterado para: ");
  Serial.println(led_status);
  digitalWrite(LED_PIN, led_status);
}

// Lê do firebase: Delay
void readDelayFirebase(){
  fb_delay = Firebase.getInt("delay");
  if(fb_delay < 1000) fb_delay = 1000;
  if(fb_delay == prev_delay) return;
  Serial.print("Delay alterado para: ");
  Serial.println(fb_delay);
  prev_delay = fb_delay;
}

// Atualiza do firebase: LED
void updateFirebase(){
  if(!alterado) return;
  bool ls = !led_status;
  Firebase.setBool("LED", ls);
  Serial.print("Definindo LED no firebase: ");
  Serial.println(!led_status);
  if (Firebase.failed()) {
    Serial.print("Erro ao setar LED:");
    Serial.println(Firebase.error());
    return;
  }
  nodemcuObject["action"] = ls;
  Firebase.push("users", nodemcuObject);
  alterado = false;
  attachInterrupt(BTN_PIN, readBtn, FALLING);
}

void readBtn(){
  Serial.println("Alterando LED via interrupt");
  alterado = true;
  detachInterrupt(BTN_PIN);
}

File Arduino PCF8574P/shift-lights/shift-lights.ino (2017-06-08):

/*  Example sketch for the PCF8574 for the purposes of showing how to use the interrupt-pin.

    Attach the positive lead of an LED to PIN7 on the PCF8574 and the negative lead to GND,
    a wire from Arduino-pin 13 to pin 3 on the PCF8474, a wire from the int-pin on the PCF8574
    to Arduino-pin 7 and wires for SDA and SCL to Arduino-pins 2 and 3, respectively.

    If all goes well you should see the small blue LED on the ESP-module lighting up and the
    LED connected to the PCF going off, and vice versa. */

#include <pcf8574_esp.h>

/*  We need to set up the I2C-bus for the library to use */
#include <Wire.h>

// Initialize a PCF8574 at I2C-address 0x20
PCF857x pcf8574(0x20, &Wire);

//If you had a PCF8575 instead you'd use the below format
//PCF857x pcf8575(0x20, &Wire, true);

bool volatile PCFInterruptFlag = false;

void PCFInterrupt() {
  PCFInterruptFlag = true;
}

void setup() {
  Serial.begin(115200);
  delay(5000);
  pinMode(13, OUTPUT);

  Wire.begin();
  //Specsheets say PCF8574 is officially rated only for 100KHz I2C-bus
  //PCF8575 is rated for 400KHz
  Wire.setClock(100000L);
  pcf8574.begin();
  // Most ready-made PCF8574-modules seem to lack an internal pullup-resistor, so you have to use the MCU-internal one.
  pinMode(2, INPUT_PULLUP);
  pcf8574.resetInterruptPin();
  pcf8574.write(7, HIGH);
  attachInterrupt(digitalPinToInterrupt(2), PCFInterrupt, FALLING);
}

void loop() {
  if(PCFInterruptFlag){
    pcf8574.rotateLeft(1);
    PCFInterruptFlag=false;
  }
  Serial.println(F("Blink."));
  if(digitalRead(13)==HIGH) digitalWrite(13, LOW);
  else digitalWrite(13, HIGH);
  delay(1000);
}

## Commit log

2017-04-16 commit inicial do projeto Plug.ar
    [18Tooth-GT2-Pulley_8MM.stl, 28by_5mm_to_8mm.SLDPRT, 28by_5mm_to_8mm.STL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]
2017-04-16 inserindo logistica de login
2017-04-16 inserindo comentarios e alterando o estado do led
2017-04-16 terminado webapp para lâmpada
2017-04-16 corrigido layoyt de mobile
2017-04-21 updating firebase, ESP and old files
    [18Tooth-GT2-Pulley_8MM.stl]
2017-06-08 adicionado segunda etapa do projeto
    [18Tooth-GT2-Pulley_8MM.stl, 28by_5mm_to_8mm.SLDPRT, 28by_5mm_to_8mm.STL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]
2017-06-08 alterando docx para pdf
